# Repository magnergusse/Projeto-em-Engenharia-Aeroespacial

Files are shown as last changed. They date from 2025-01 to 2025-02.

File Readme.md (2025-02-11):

# Projeto-em-Engenharia-Aeroespacial

[EN]This project consisted on the design and development of aerial vehicles capable of reconfiguring in flight in order to join forces to perform greater tasks. It was not possible to conclude said project but it showed to be a great lesson and stepping stone in this journey, which would not have been possible without the help of my colleague Alexandre Silva and our Professor, Pedro Casau.

[PT] Este projeto consistiu no design e desenvolvimento de veículos aéreos capazes de se reconfigurarem em voo de forma a unirem esforços para a realização de tarefas de maior dimensão. Não foi possível concluir o referido projecto mas revelou-se uma grande lição e um trampolim neste percurso, que não teria sido possível sem a ajuda do meu colega Alexandre Silva e do nosso Professor, Pedro Casau.

<h2>Gallery</h2>
<p align="center">

  <br>
    
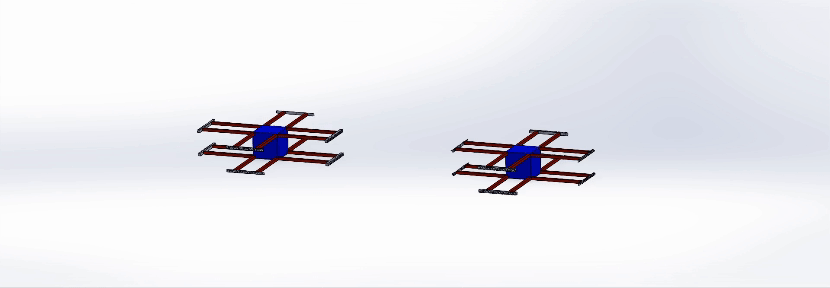
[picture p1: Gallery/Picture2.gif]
    
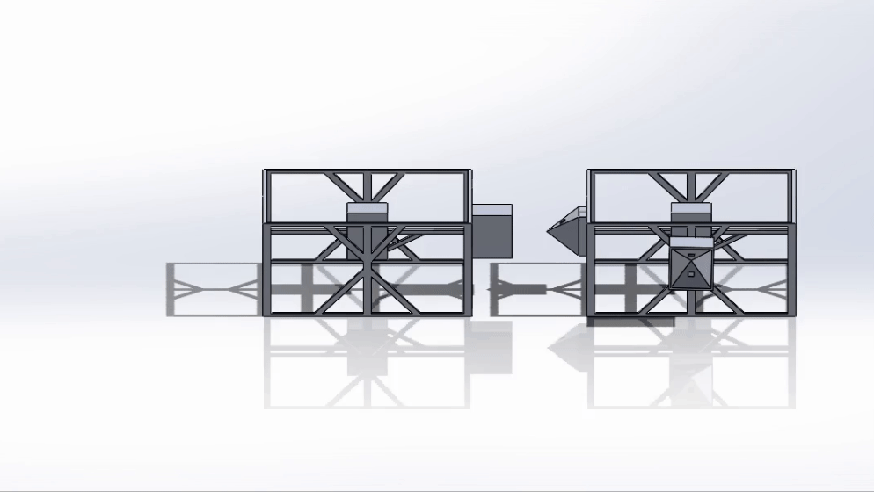
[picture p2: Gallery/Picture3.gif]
    
      <br>
<!---   <a>
  Concept 1   |      
  </a>
  <a>
   Concept 2    |      
  </a> 
  <a>
  Concept 3
  </a>
  --->
  <br>
  
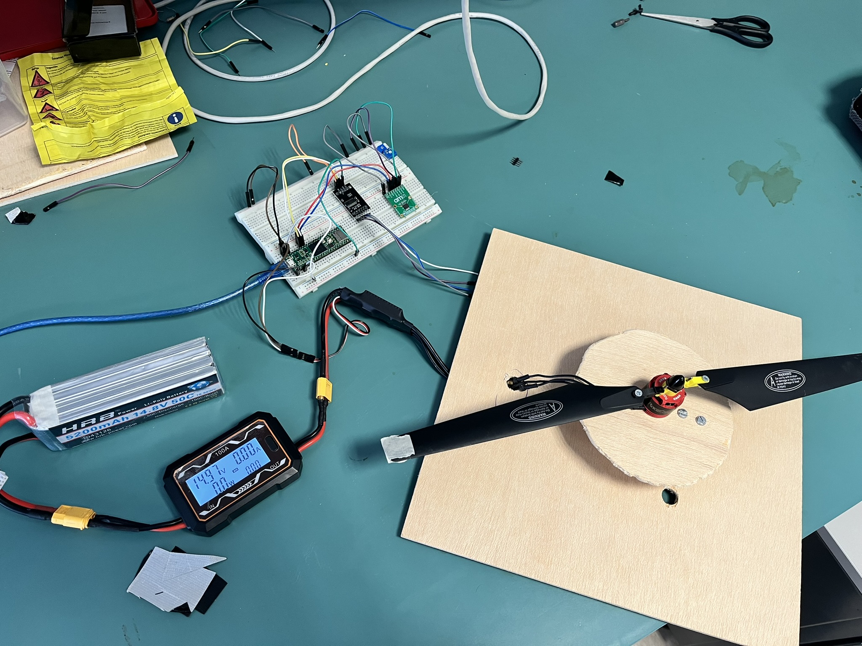
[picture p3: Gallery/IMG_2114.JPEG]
  
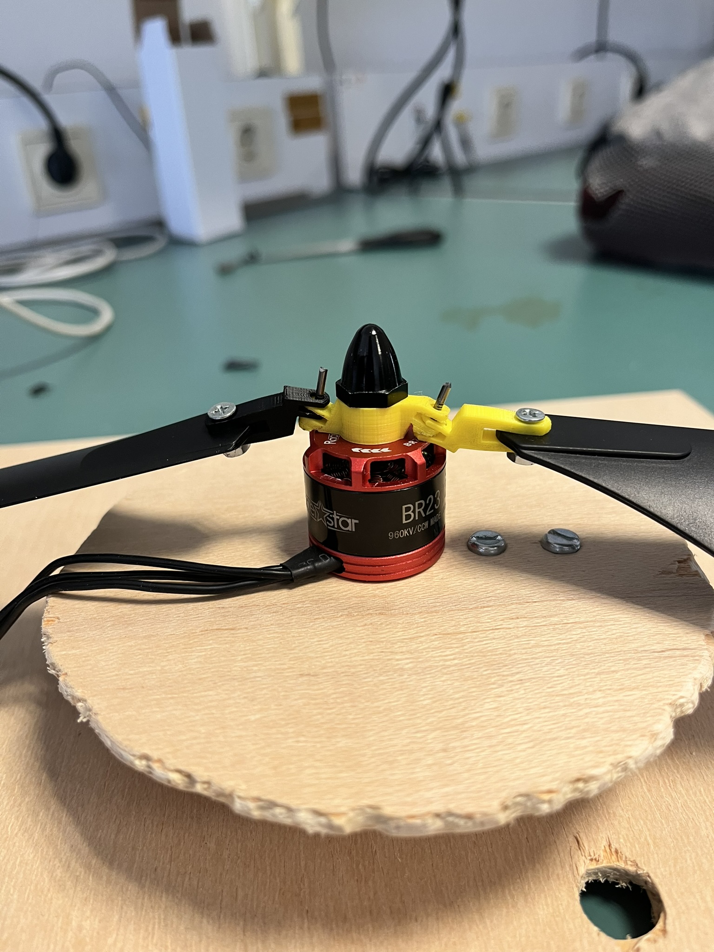
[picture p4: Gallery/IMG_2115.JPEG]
  
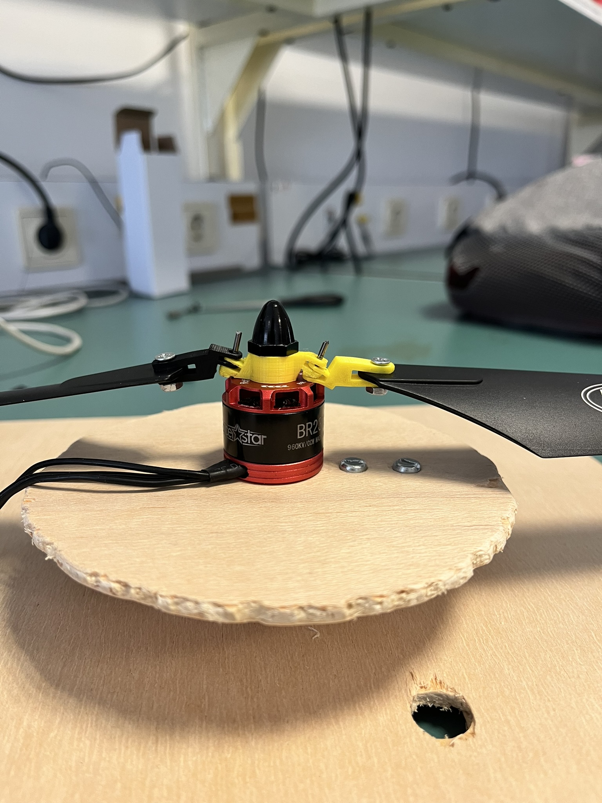
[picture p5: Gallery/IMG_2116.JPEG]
  
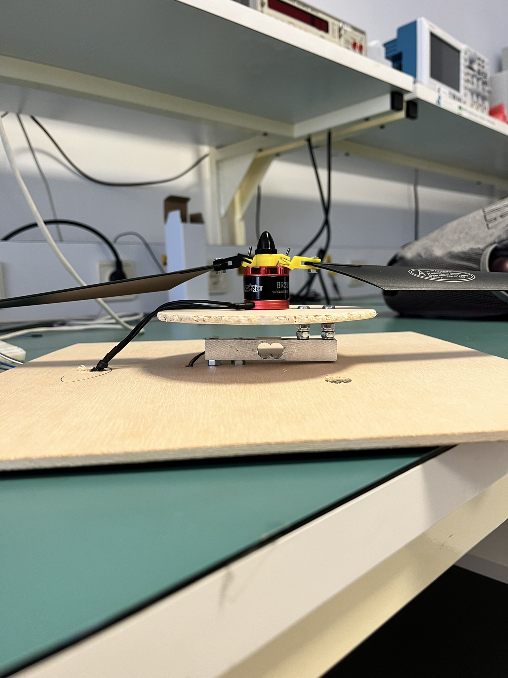
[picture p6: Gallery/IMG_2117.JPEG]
  
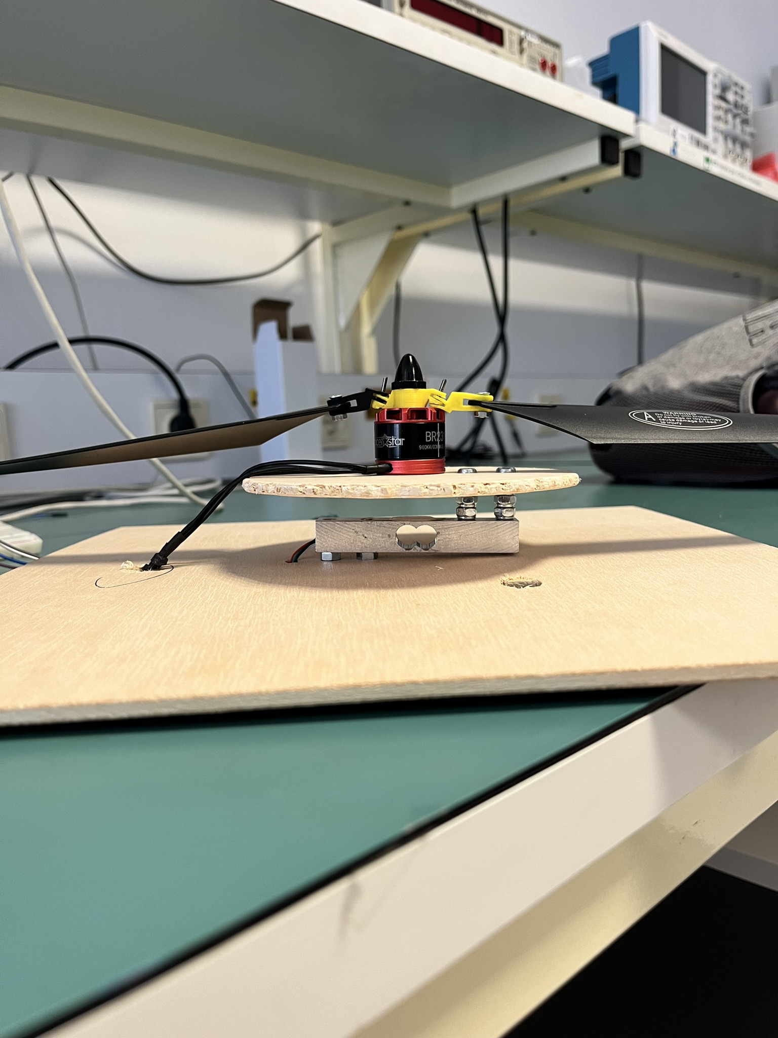
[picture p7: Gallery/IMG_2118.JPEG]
  
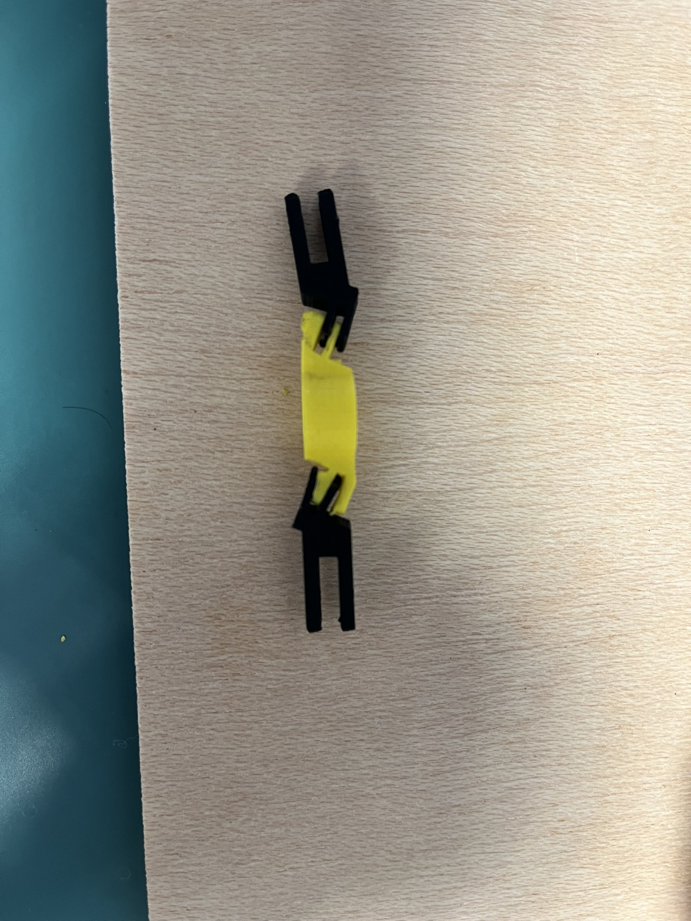
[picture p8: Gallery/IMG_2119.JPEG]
  
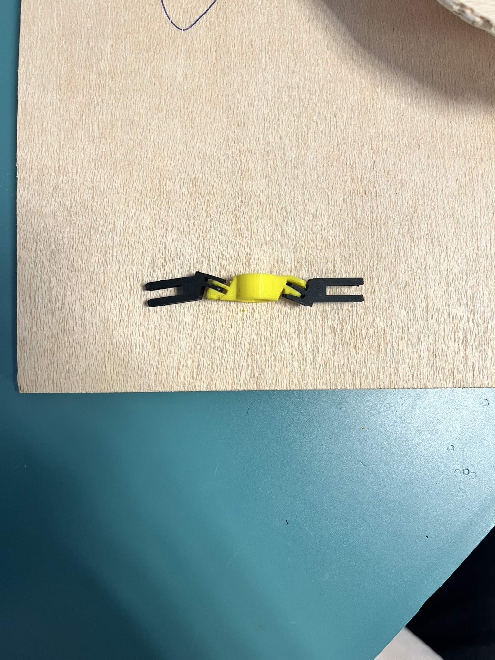
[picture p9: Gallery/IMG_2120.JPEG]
  
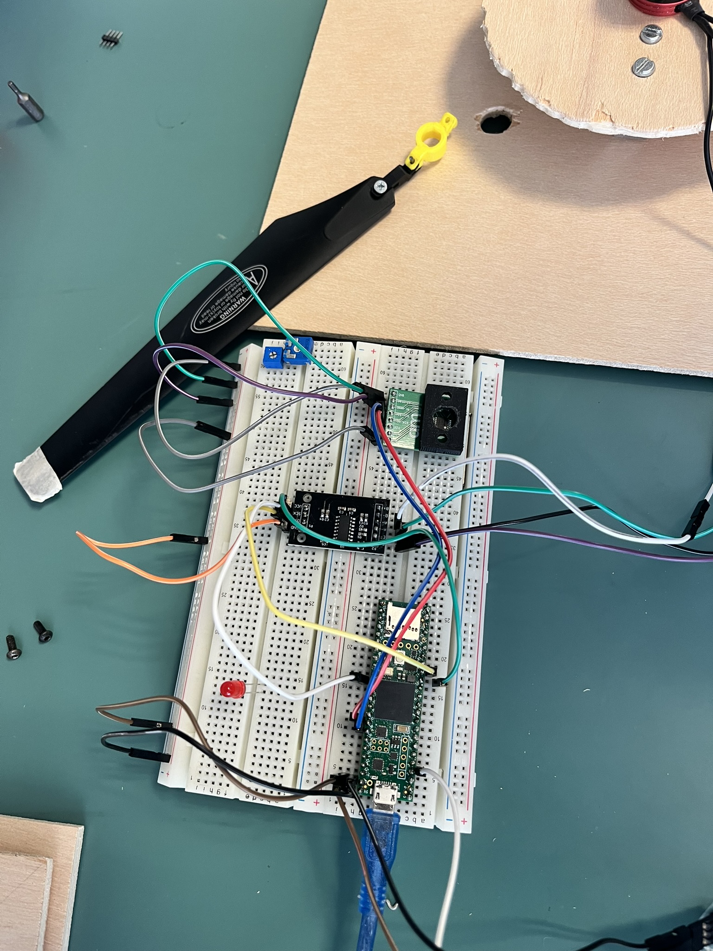
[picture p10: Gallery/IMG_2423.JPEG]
  
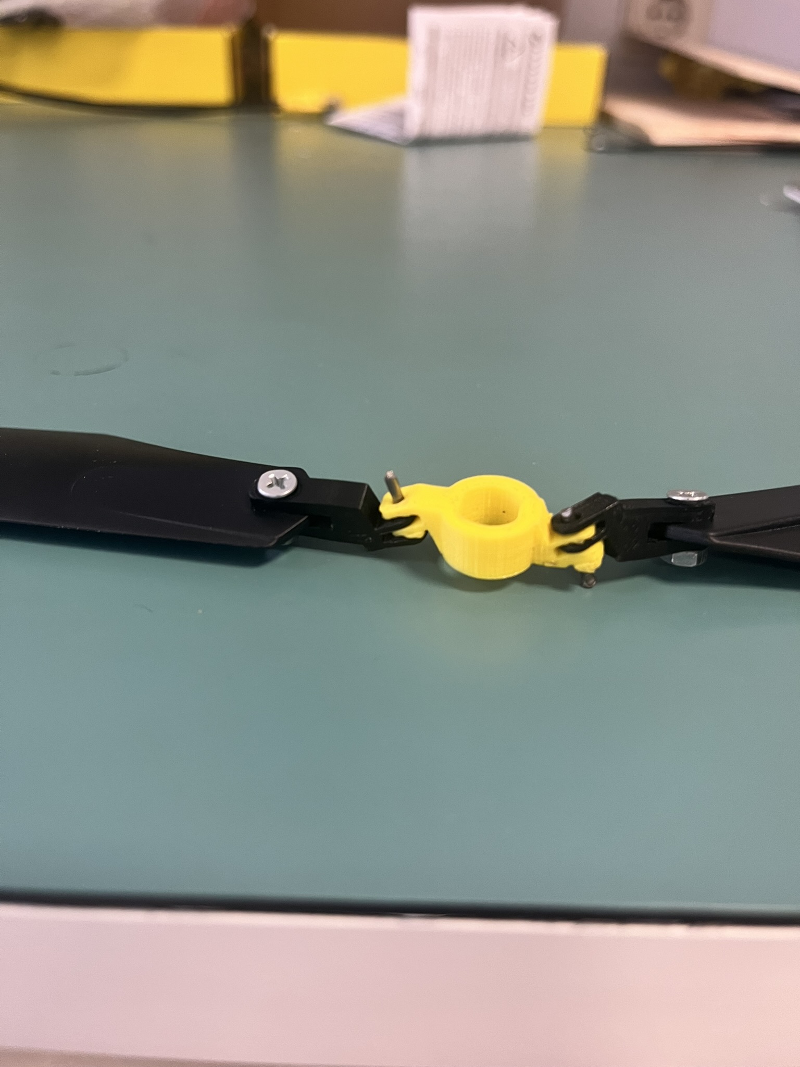
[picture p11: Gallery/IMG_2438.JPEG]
  
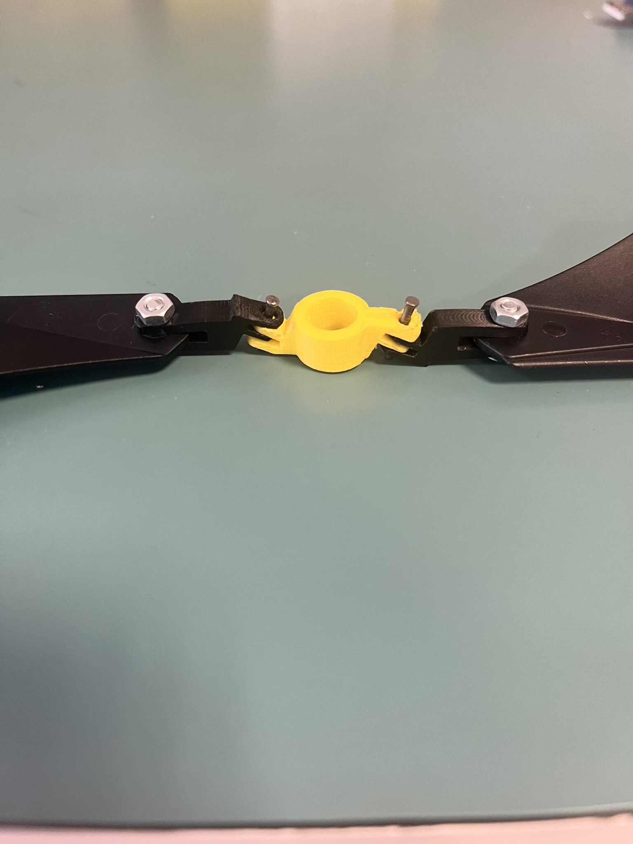
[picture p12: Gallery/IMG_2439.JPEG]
  
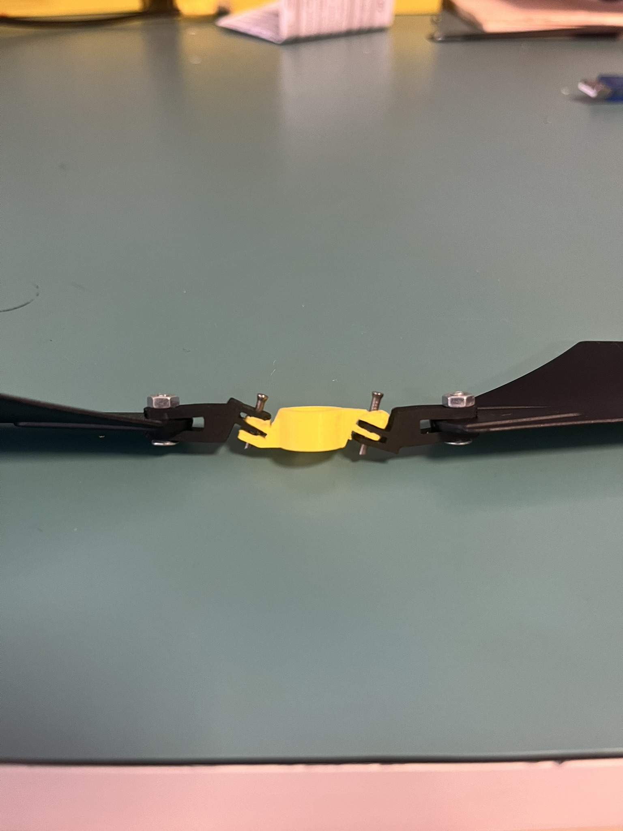
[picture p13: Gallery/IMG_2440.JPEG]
  
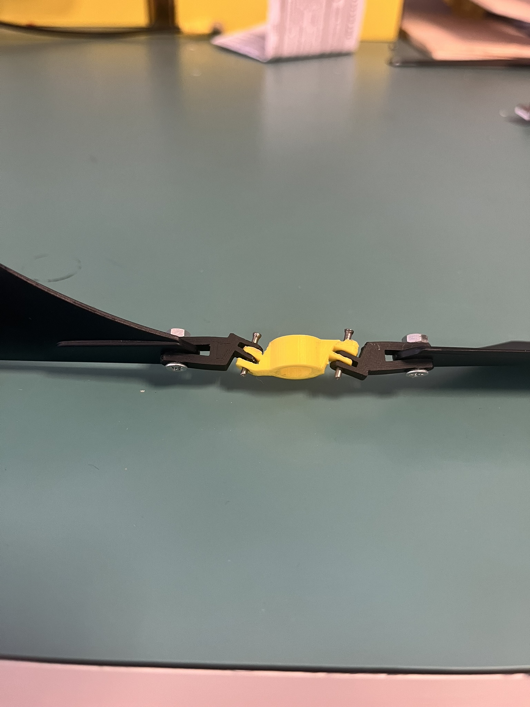
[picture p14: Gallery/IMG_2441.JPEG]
  
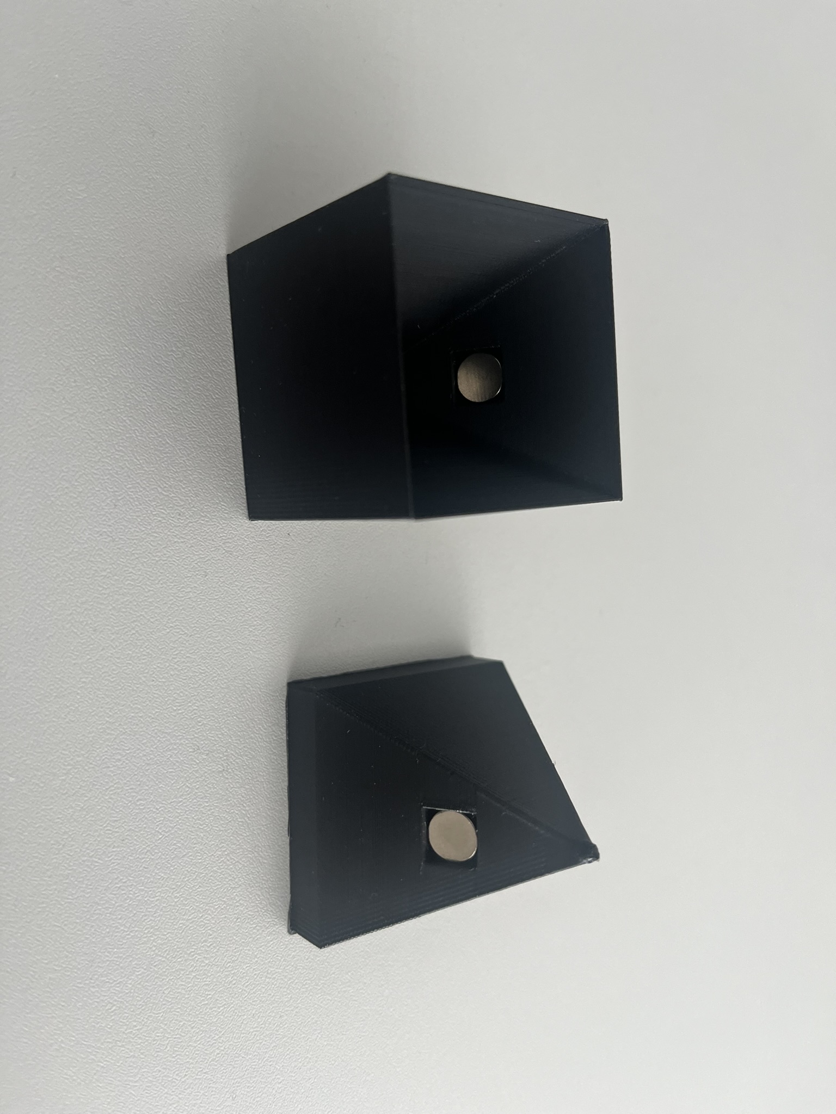
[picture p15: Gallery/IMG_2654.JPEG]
  
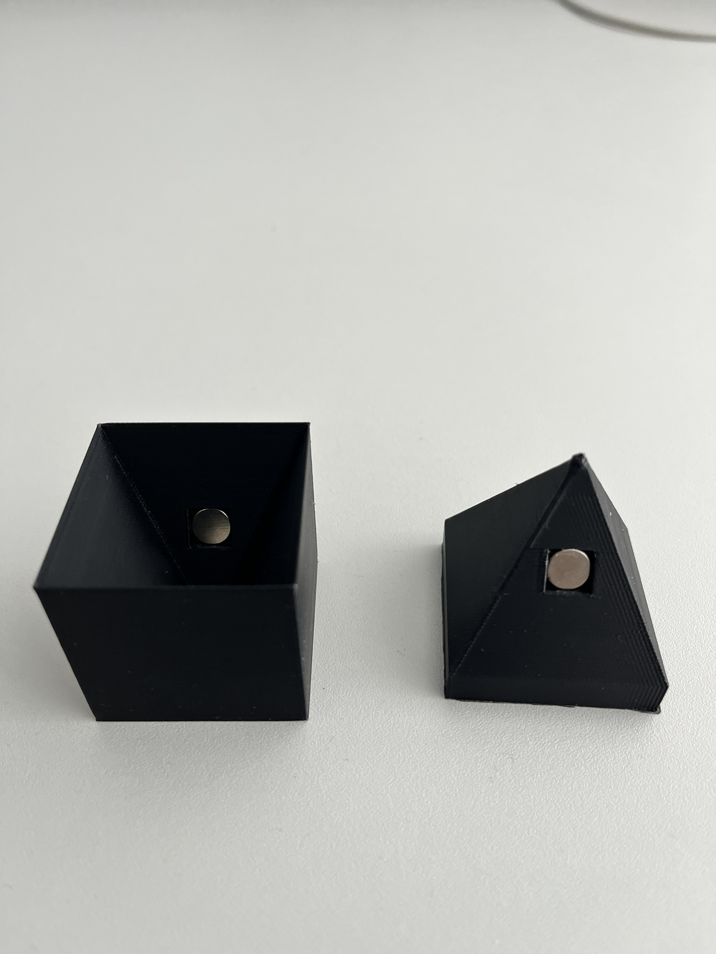
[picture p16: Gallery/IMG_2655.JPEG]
  
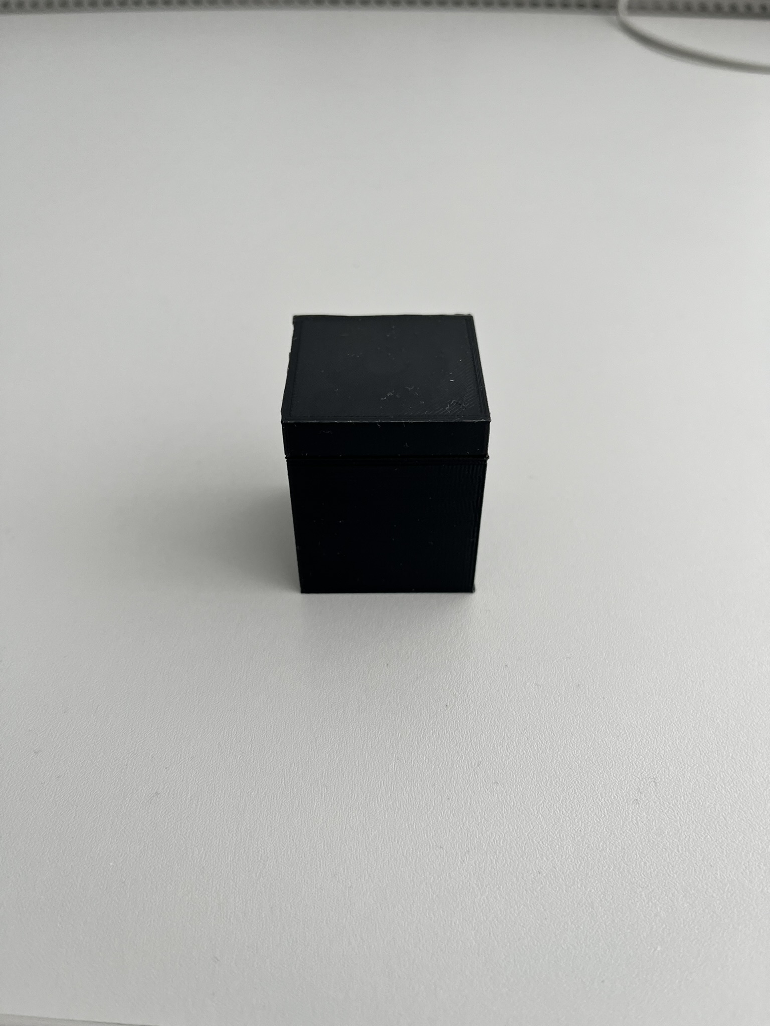
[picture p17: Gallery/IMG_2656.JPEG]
  
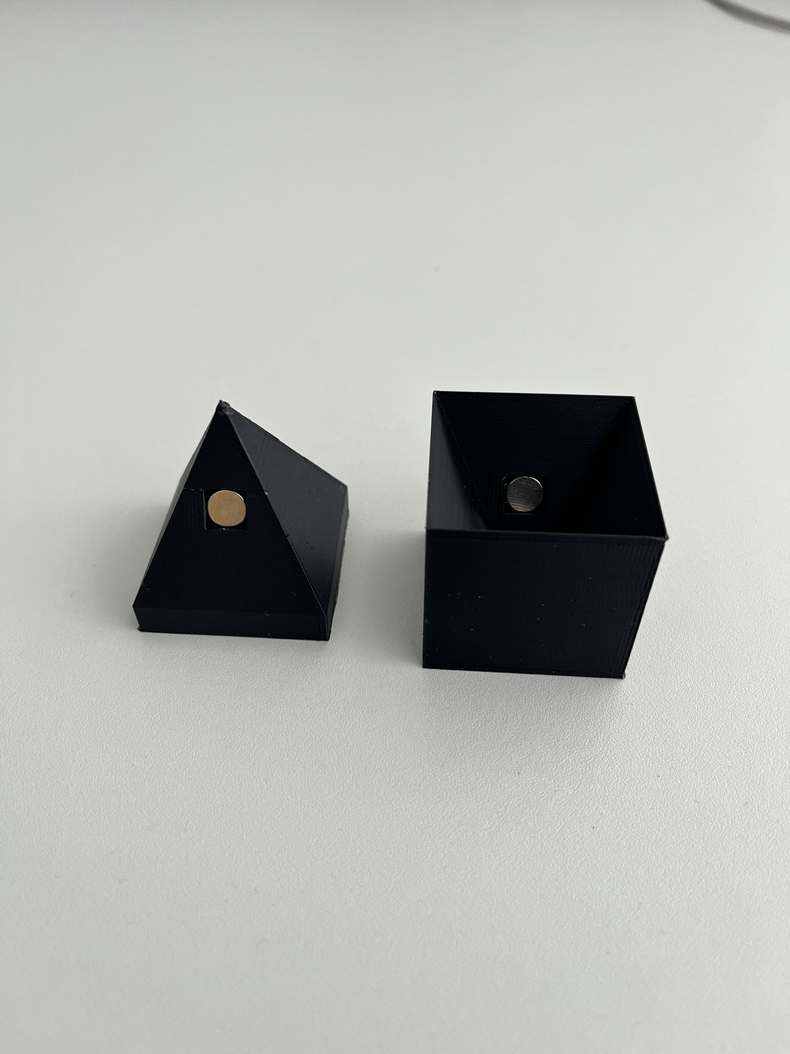
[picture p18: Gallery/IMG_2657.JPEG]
  
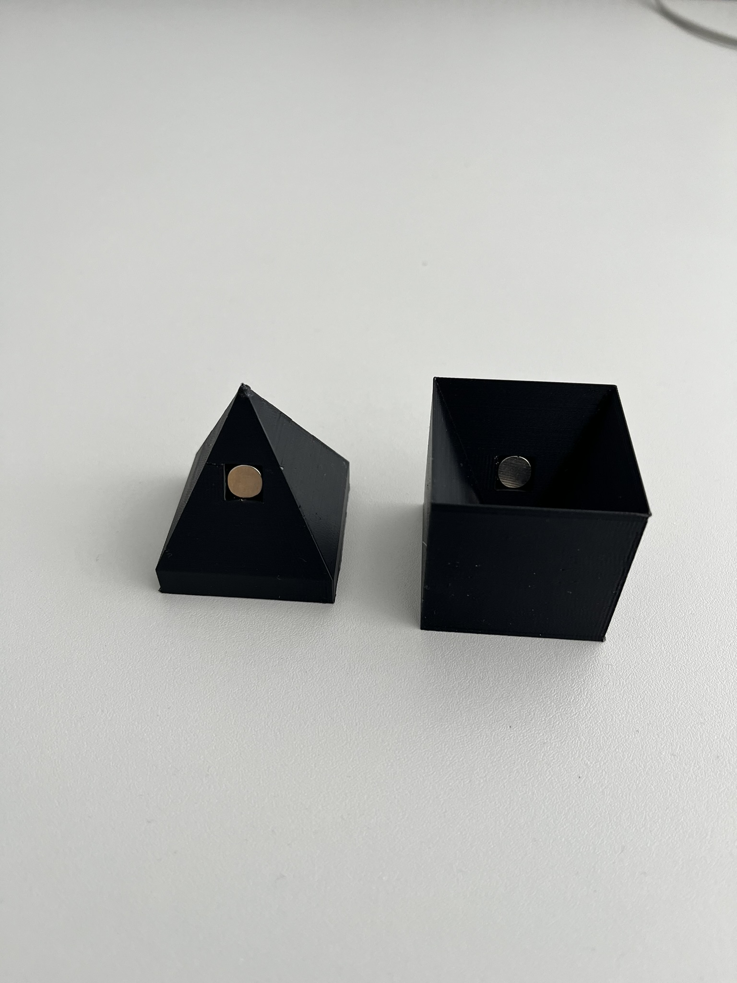
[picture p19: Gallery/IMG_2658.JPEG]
  
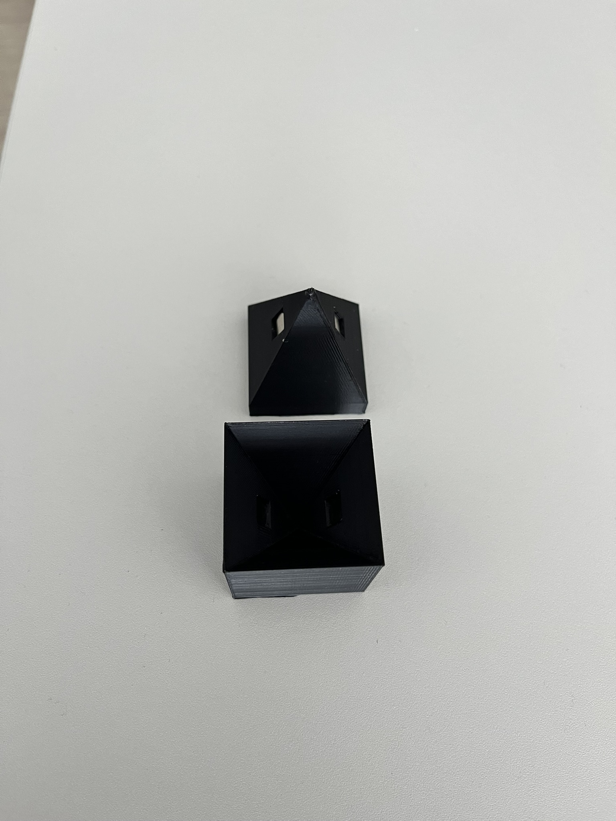
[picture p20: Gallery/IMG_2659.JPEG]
  
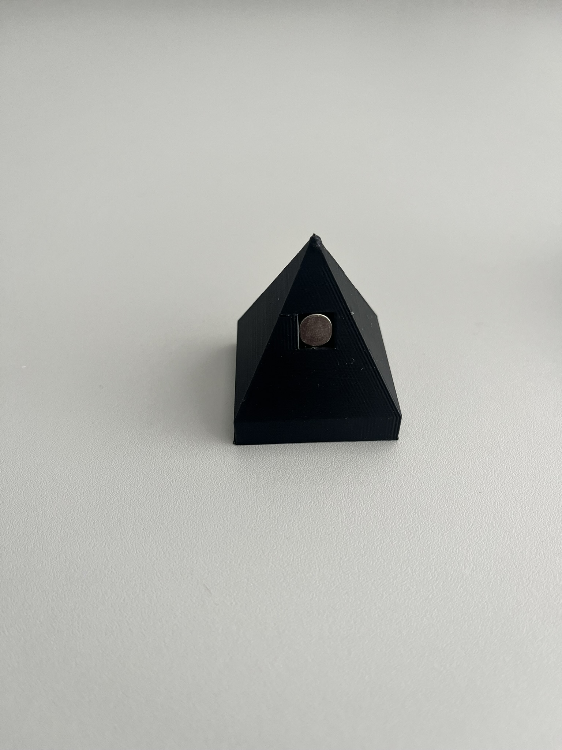
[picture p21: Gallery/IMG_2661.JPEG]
  
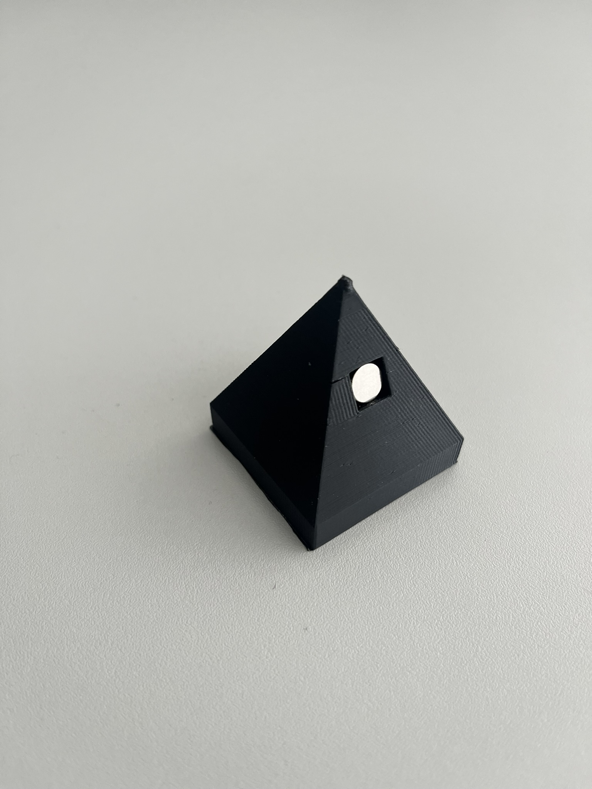
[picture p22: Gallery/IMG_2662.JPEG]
  
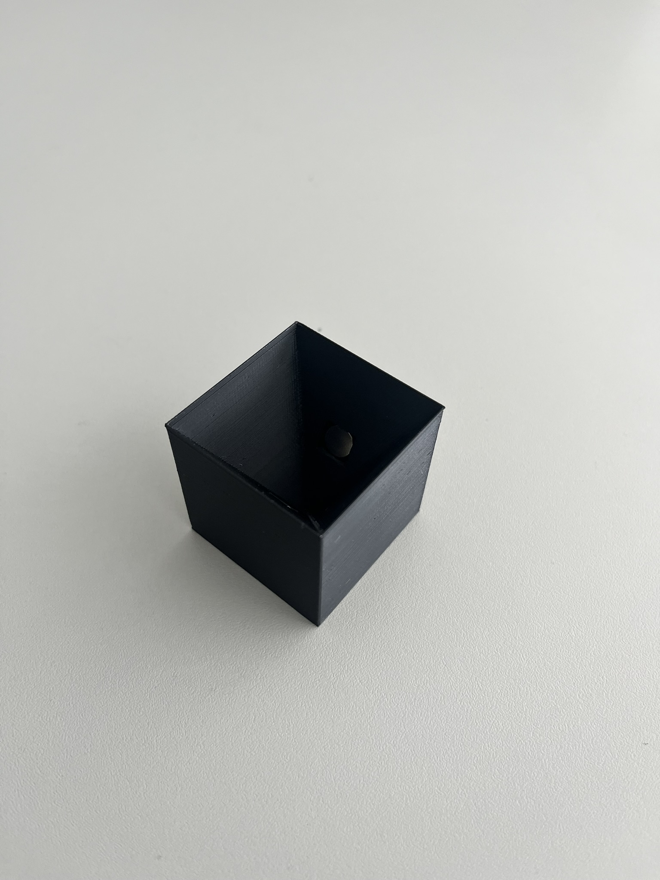
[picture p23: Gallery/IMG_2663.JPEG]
  
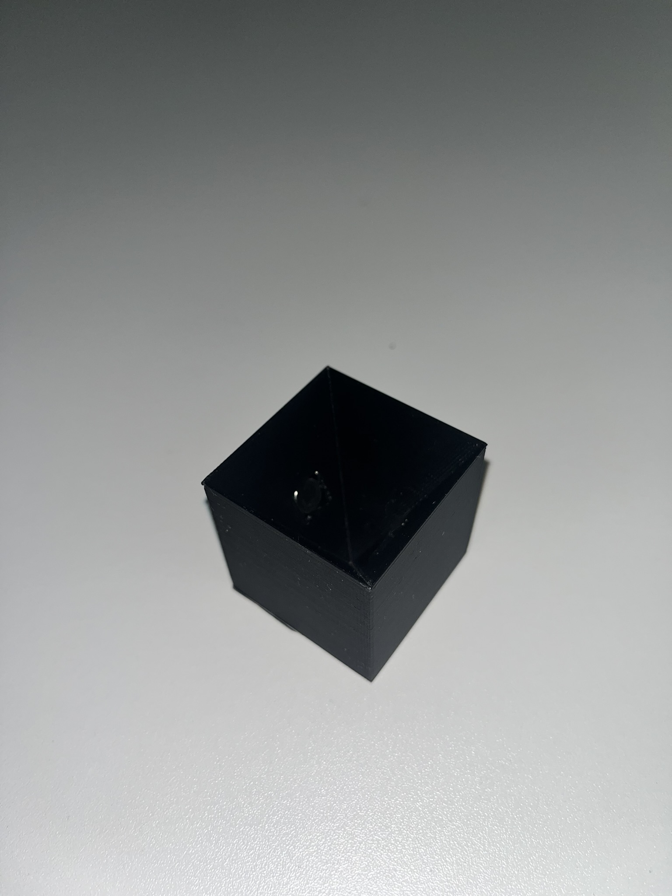
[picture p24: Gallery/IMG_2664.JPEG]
  
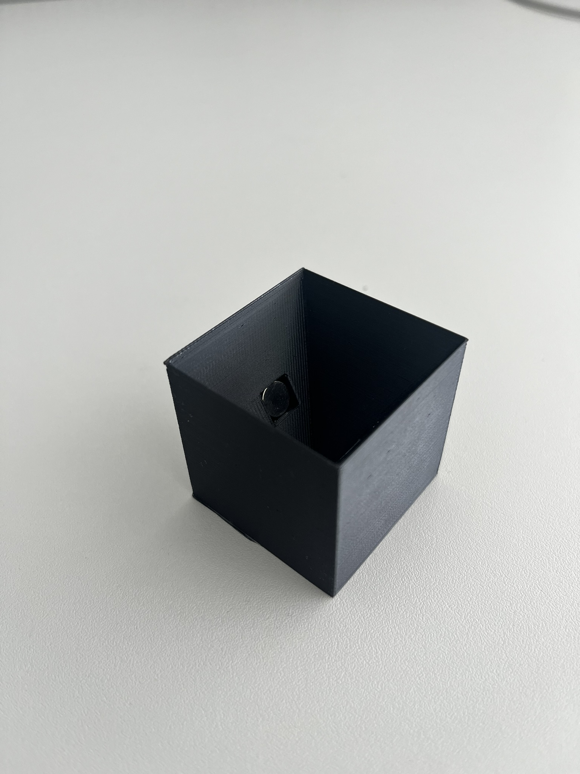
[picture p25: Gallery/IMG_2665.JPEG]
  
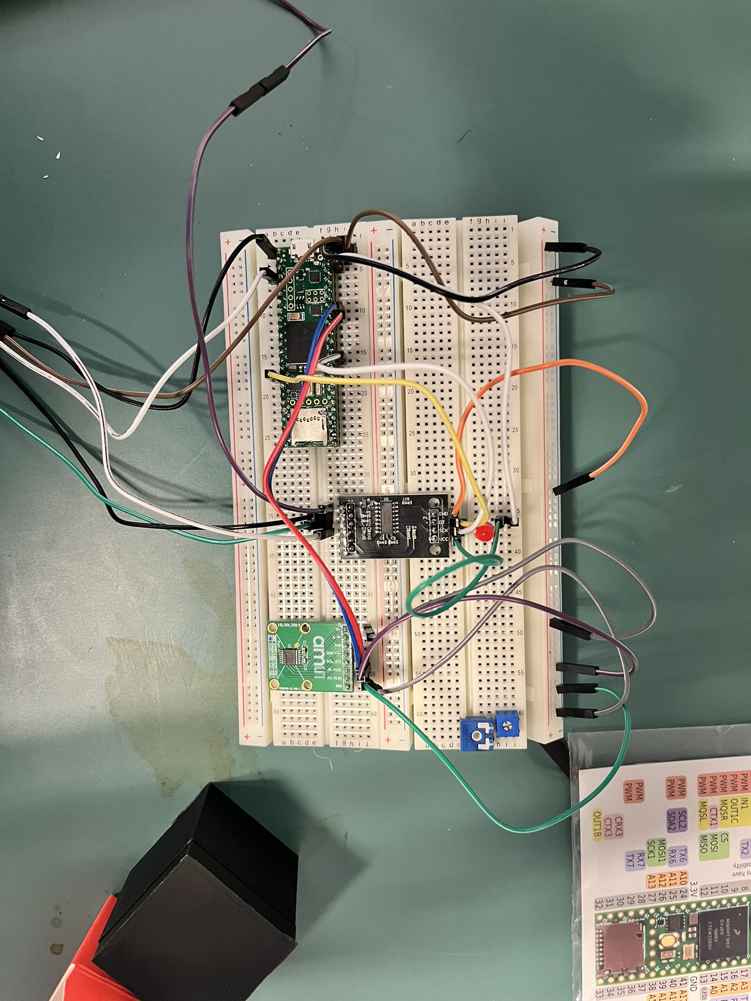
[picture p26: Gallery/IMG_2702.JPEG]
  
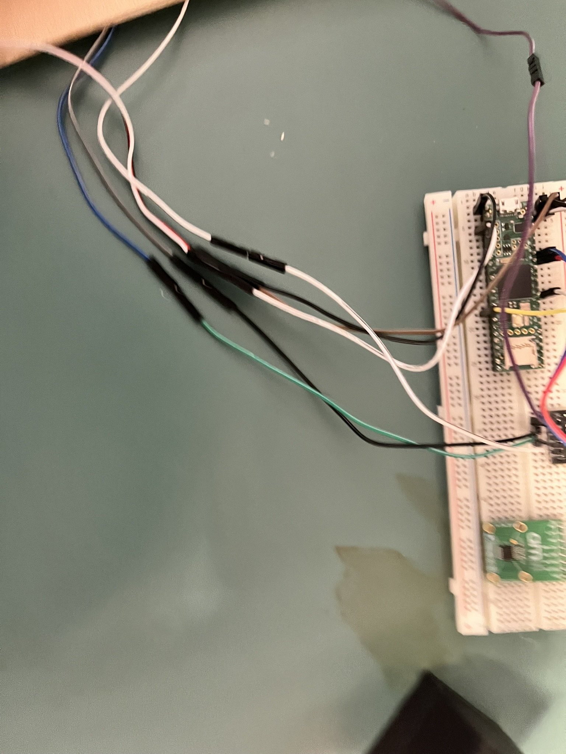
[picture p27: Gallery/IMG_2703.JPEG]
  
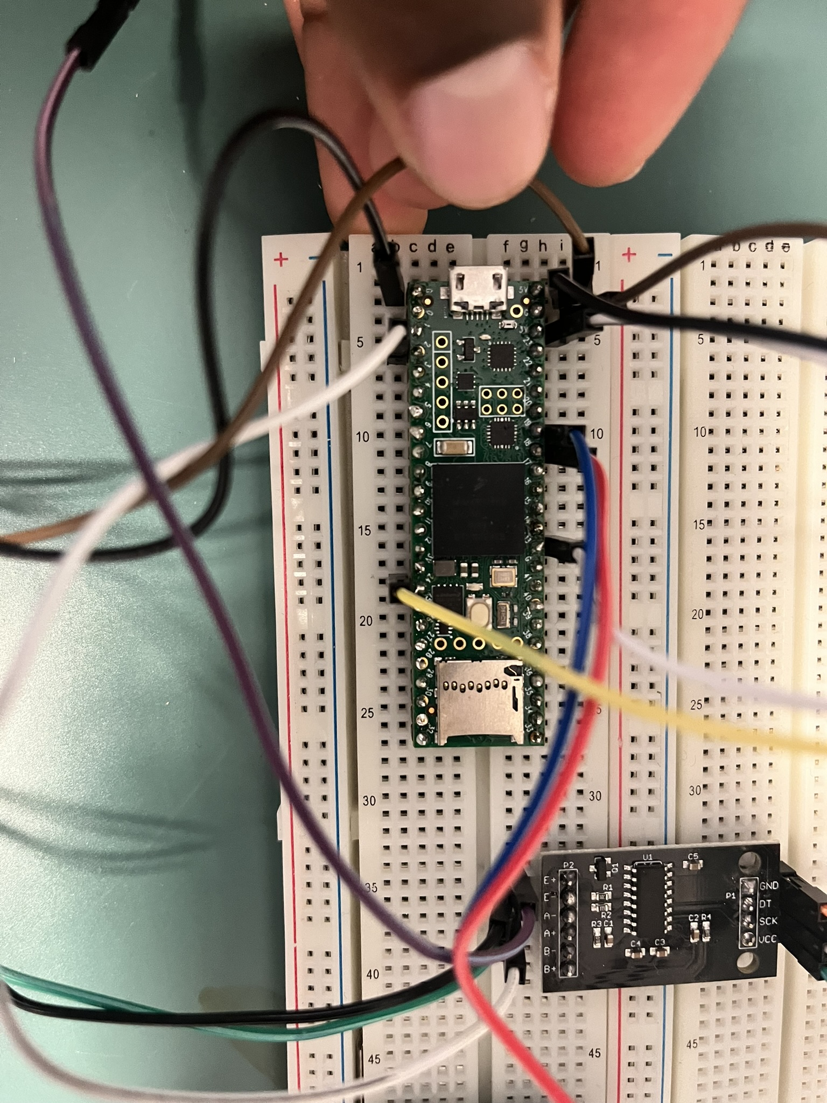
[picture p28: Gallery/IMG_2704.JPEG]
  
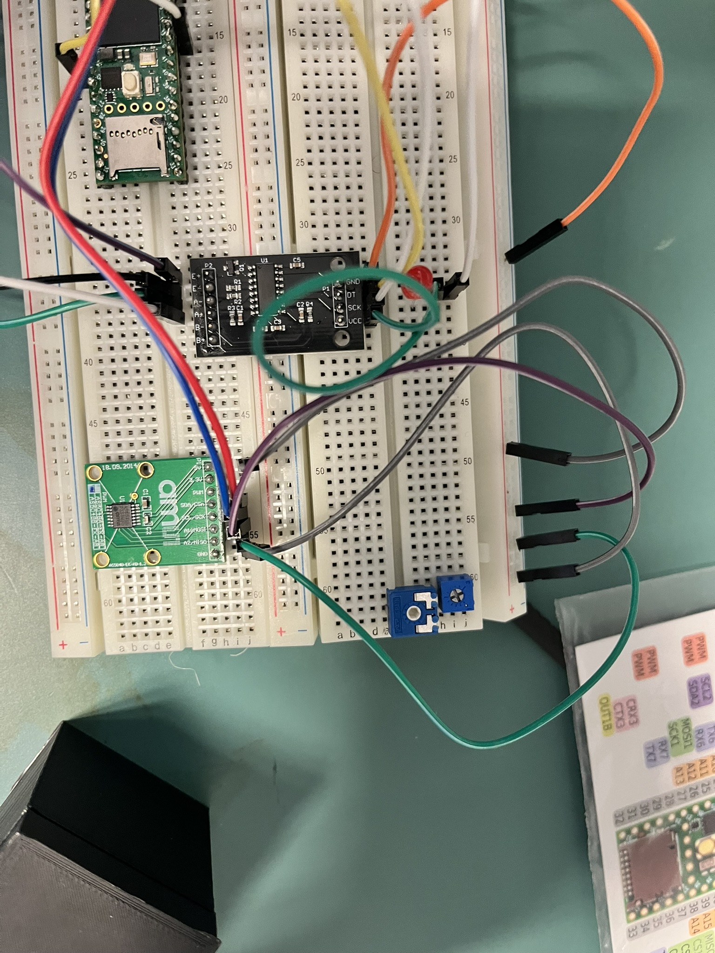
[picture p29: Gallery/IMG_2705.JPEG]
  
  
</p>

<h2>Videos</h2>
  <p align="center">

   <a href="https://youtube.com/shorts/ozo2lfBxjCk?feature=share" target="_blank">
     
  </a>
  
  <a href="https://youtube.com/shorts/JcyohlVHpi4?feature=share" target="_blank">
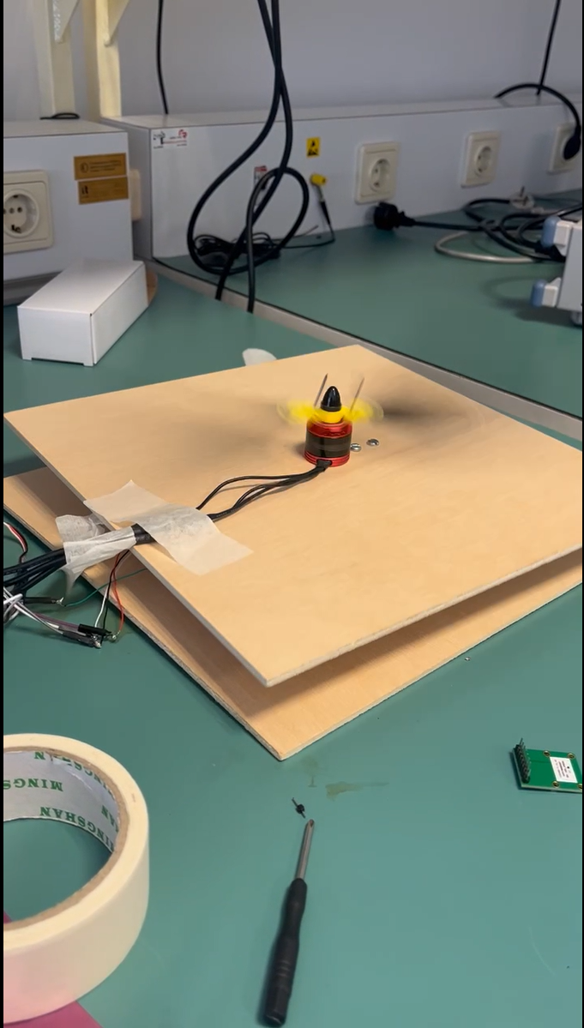
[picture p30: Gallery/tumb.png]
    
  </a>
  
  <a href="https://youtube.com/shorts/KsTUEmDCxvE?feature=share" target="_blank">
    
  </a>
  <br>
   <a>
    Reconfiguration Mechanism    |      
  </a>
  
  <a>
      Thrust Stand 1    |      
  </a>
  
  <a>
      Thrust Stand 2
  </a>
</p>

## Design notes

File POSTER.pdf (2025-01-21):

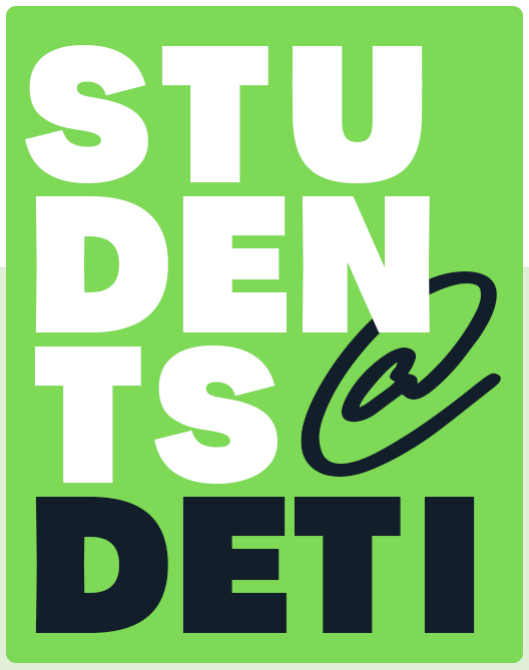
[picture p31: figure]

# Development of Modular Aerial reconfigurable Vehicles

## Alexandre Silva, Magner Gusse Orientador: Prof. Pedro Casau

Projeto em Engenharia Aeroepacial, 3º ano, LEA.
2024

Abstract

This study proposes the development of a modular reconfigurable aerial vehicle. Simply, this project is proposes the creation of 2 aerial vehicles that can attach to each other. Some of the challenges and objectives of this study were the use of coaxial rotors using Swashplateless[1] system which was the focal point of this project.

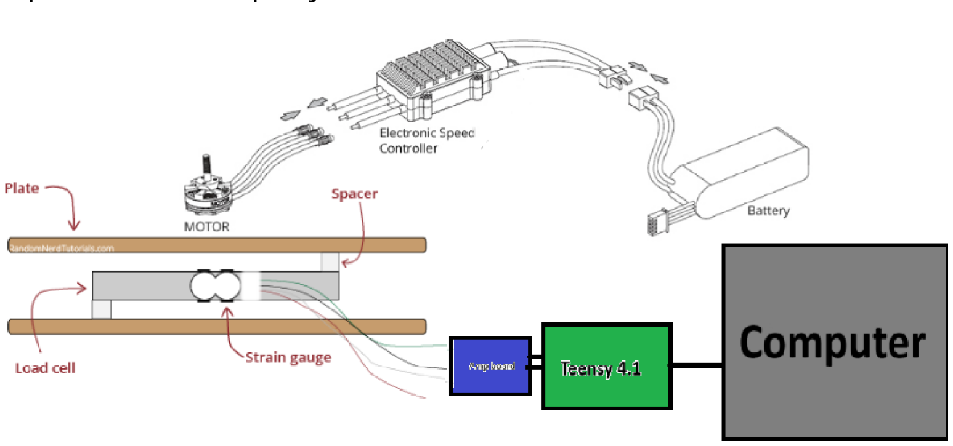
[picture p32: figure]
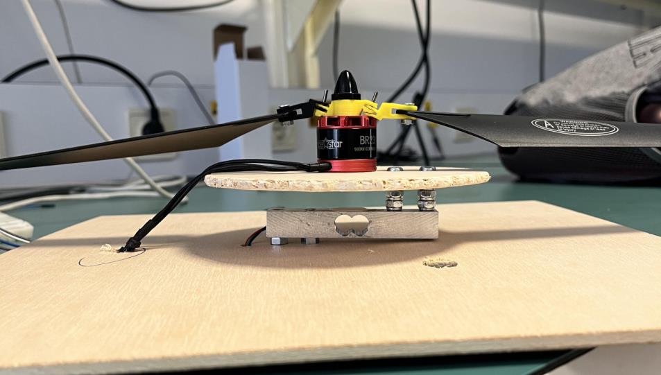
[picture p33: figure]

Fig 1- Thrust Stand Setup
a)Schematic | b)Actual setup

Methods
One of the objectives of this project was to implement coaxial rotors for propulsion and Swashplateless system for direction.
- It was necessary to use helicopter blades instead of regular drone blades, in addition, based on research over the configurations to implement on the model of the system
- The configuration chosen was 65º, which is considered the one that is easier to command and understand[2].
The steps towards determining the propulsion of the system, were to implement a thrust stand with a simple design, using a teensy 4.1 microcontroller, a load cell, wood plates, the motor, blades, the Swashplateless design and a breadboard for all electronics[Fig 1].

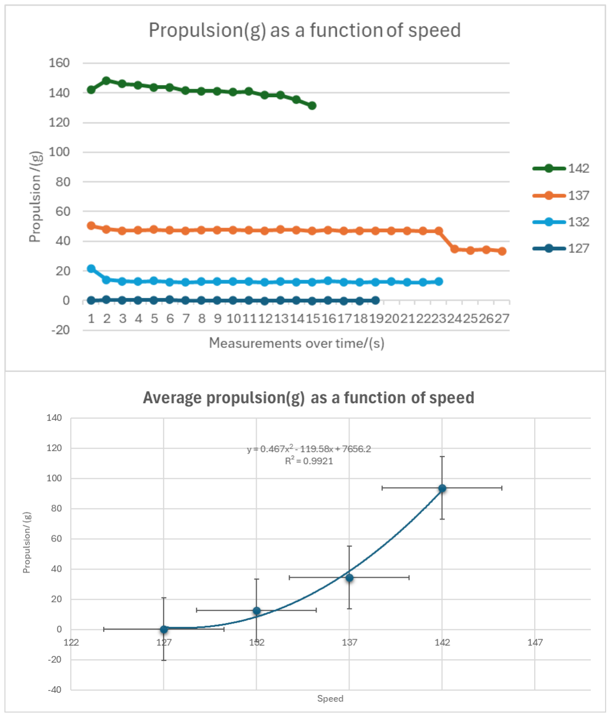
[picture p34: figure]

With this setup it was possible to extract data from series of tests and determine the curve between the propulsion and the power of the motor, from which is possible to predict the maximum thrust possible with this combination of motor and propellers [Fig 2].
To further use the Swashplateless system , it is necessary to have a magnetic encoder to determine the motor angle which would further be used for the control of the pitch and roll movements of the system.
Conclusion
- It was possible to learn how the Swashplateless system can be implemented, by studying the necessary components and different model structures.
- The propulsion curve for the combination of motor and blades was determined using the thrust stand.
This project represents a great learning curve for the involved and sets stones for further implementations. References
[1] Paulos, J., & Yim, M. (Year). Flight Performance of a Swashplateless Micro Air Vehicle.
[2] Stanton, T. (2020). Drone Helicopter Hybrid https://www.youtube.com/watch?v=d80oXSCcHTk

Fig 2- Thrust tests results.

a)

b)

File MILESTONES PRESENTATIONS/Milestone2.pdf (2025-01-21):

Milestone 2

# Design and Development of a Modular Reconfigurable Aerial Vehicle

Grupo 6
107957 – Alexandre Silva
110180 – Magner Gusse

12/12/2023

Pedro Casau

Orientador:

# Conteúdos

Contexto 1 Contextualização da missão,

Objetivos e requisitos | 3

### Progressos

Estado atual do projeto

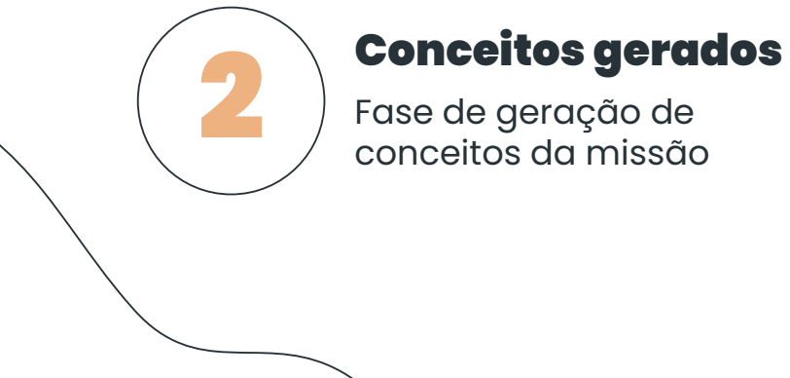
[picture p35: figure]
Conceitos gerados Fase de geração de conceitos da missão

4

### Próximos passos

Testes e objetivos a
alcançar nas próximas
fases

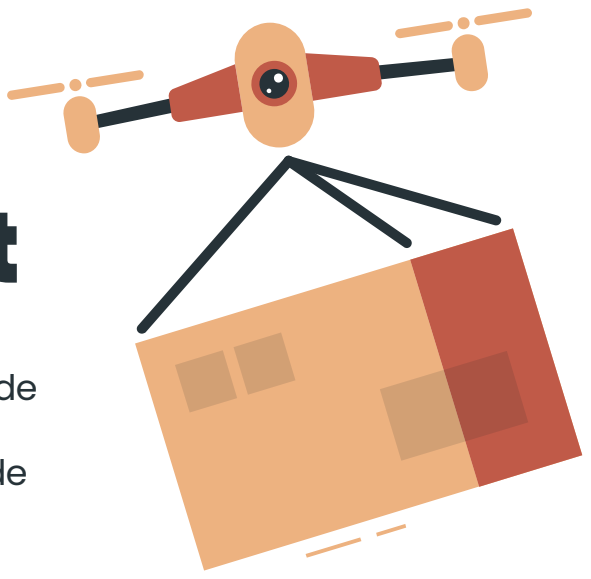
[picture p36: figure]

# Mission Statement

Construção de veículos aéreos que funcionam de forma individual, capazes de se juntar em voo formando configurações diferentes e capazes de em conjunto realizar diversas tarefas.

Primários:

- Desenvolver dois módulos independentes e capazes de realizar as reconfigurações em voo.
- Estudo, comparação e seleção dos métodos de acoplamento de módulos. Secundários:
- Rotores uni-axiais(Counter-Rotating).
- Demonstrar princípio científico e aplicabilidade.
- Otimização da estrutura.
- Extra: Ligação de um Payload.

# Objetivos

# Requisitos

1

### Performance

❑ Voo estável e controlado ❑ Reconfiguração em voo
❑ 6 graus de Liberdade
❑ Sistema Swashplateless

2

### Fiabilidade

❑ 10 minutos de voo
❑ Estrutura resistente
❑ Aviónica protegida
❑ Reutilizável

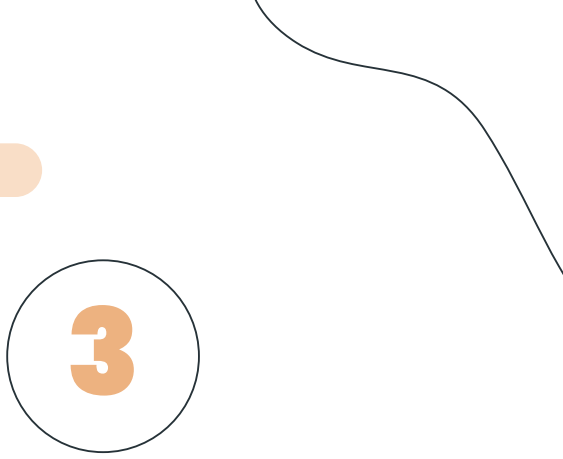
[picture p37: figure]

### Design

❑ Simplicidade de Design
❑ Fácil montagem
❑ Fácil manutenção

# Geração de conceitos

### Ligação entre módulos

Criação de propostas
para a ligação entre os
veículos

### Swashplateless

Criação de propostas
para o sistema que irá
direcionar os veículos.

1 2

# Conceitos de Ligação

### Vantagens

- Estabilidade de voo
- Massa reduzida

### Desvantagens

- Mais difícil de efetuar a ligação

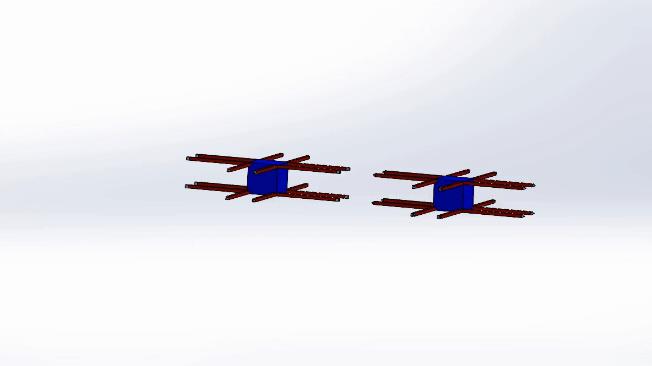
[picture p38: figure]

Conceito 1

# Conceitos de Ligação

### Vantagens

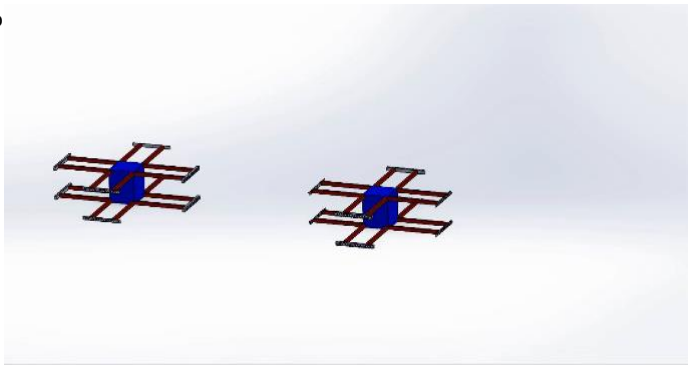
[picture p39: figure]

- Maior estabilidade de voo

### Desvantagens

- Difícil de efetuar a
ligação
- Possui mais massa

Conceito 2

# Conceitos de Ligação

### Vantagens

- Facilidade de ligação

### Desvantagens

- Menor estabilidade
- Maior massa

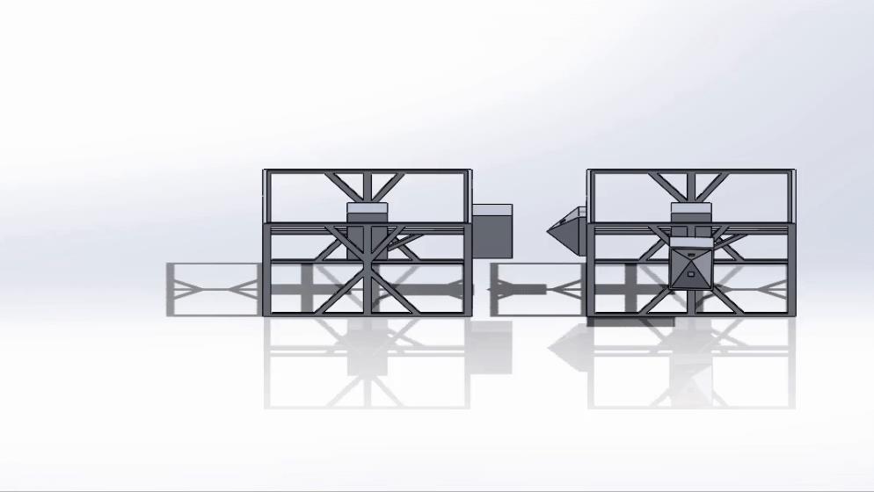
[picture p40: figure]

Conceito 3

# Conceitos de Ligação

### Estrutura da ligação

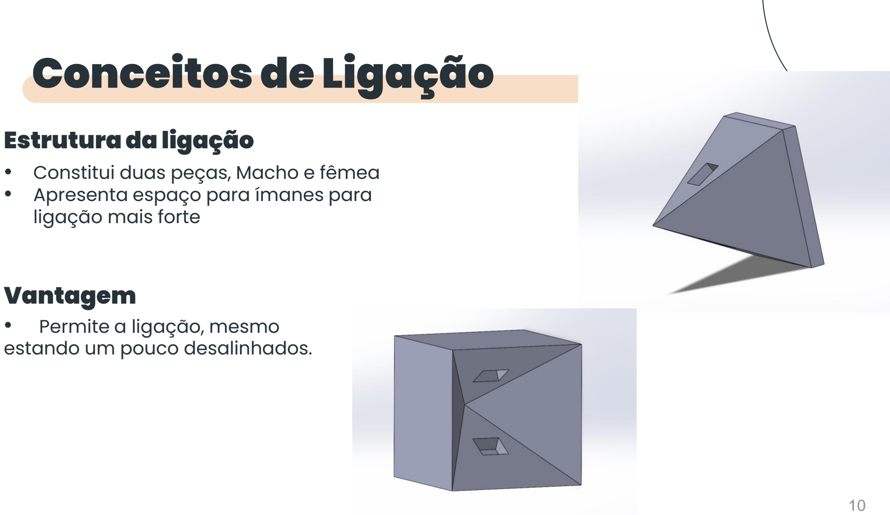
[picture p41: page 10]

- Constitui duas peças, Macho e fêmea
- Apresenta espaço para ímanes para ligação mais forte

### Vantagem

- Permite a ligação, mesmo estando um pouco desalinhados.

# Conceitos do Swashplateless

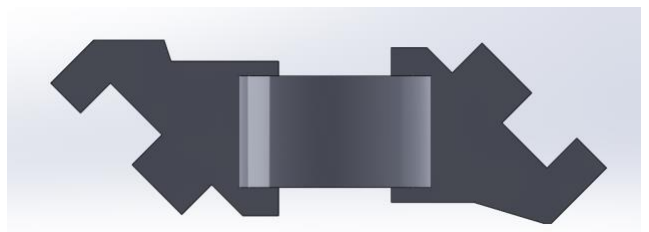
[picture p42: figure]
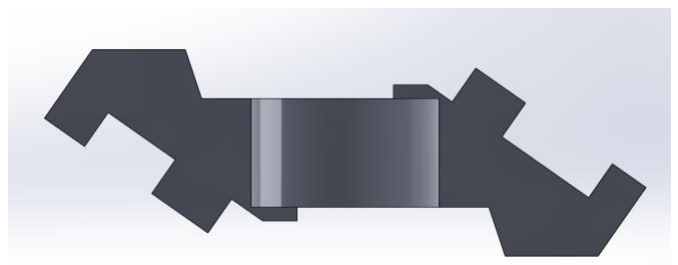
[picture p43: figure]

45º | 35º

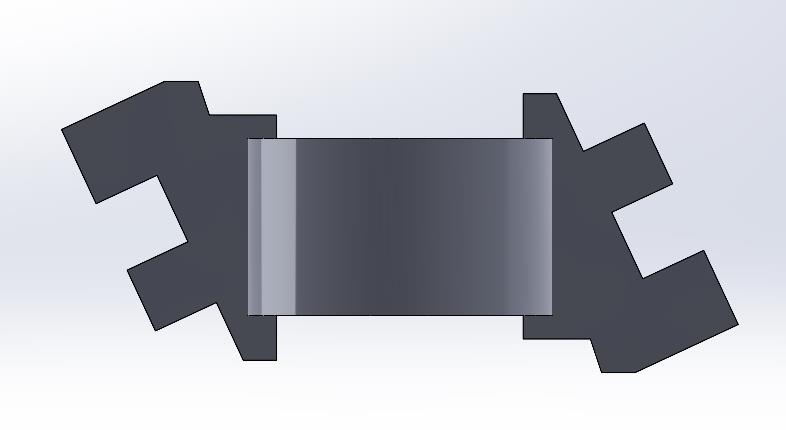
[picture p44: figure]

65º

Ângulo | Tuning | Motor Load
Maior | Fácil | Maior
Menor | Difícil | Menor

# Swashplateless

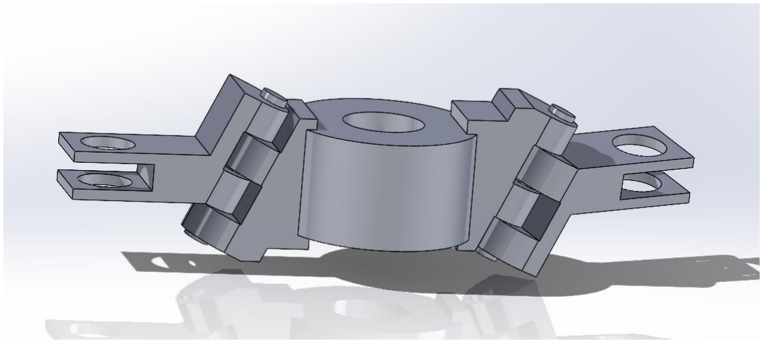
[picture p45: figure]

### Microcontrolador

# Listagem de componentes

### Bateria

### Rotores

### Hélices

4s e 5200 mAh

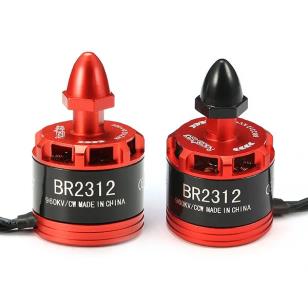
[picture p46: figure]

Brushless 1250KV

19cm de comprimento

Teensy 4.1

### Recetor

# Listagem de componentes

### Speed Controller

### Sensor de posição angular

### Transmissor

HobbyKing 50A

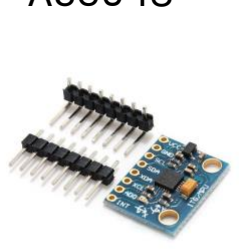
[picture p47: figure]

AS5048

FS-i6X 2.4GHz

FS-iA6B 2.4GHz

# Componentes - Massa

Componente | Qtn. | Mass(g) p/unit
Rotor | 2 | 68
ESC | 2 | 82
Teensy 4.1 | 1 | 12
Bateria | 1 | 475
Recetor | 1 | 15
Sensor | 1 | 5
Cables | n | 15
Helices | 4 | 11
Swashplateless | 1 | 10
Total | | 876

1 Módulo
Para a potência máxima de um motor, usando hélices menores, garante-se propulsão de 1200g e o requisito de 10 minutos de voo

# Arquitetura

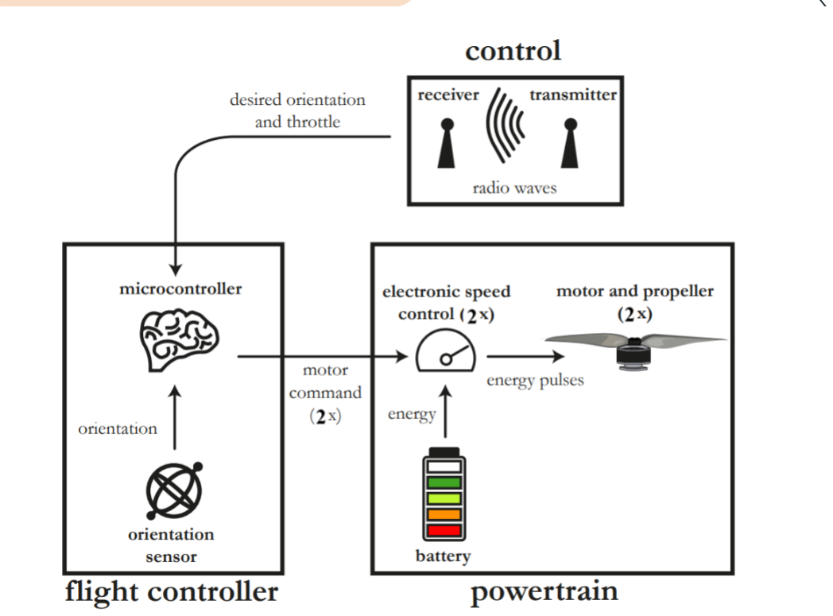
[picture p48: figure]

### Esquematização

Esquema funcional da
arquitetura eletrónica a
seguir em ambos veículos.

# Arquitetura

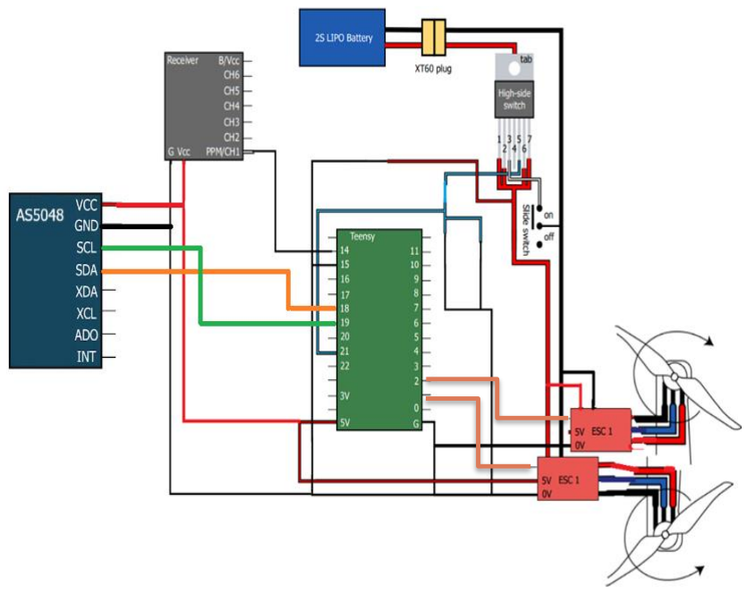
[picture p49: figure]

### Ligações dos componentes

Ligação esquematica e funcional dos componentes escolhidos.

# Work Breakdown Structure

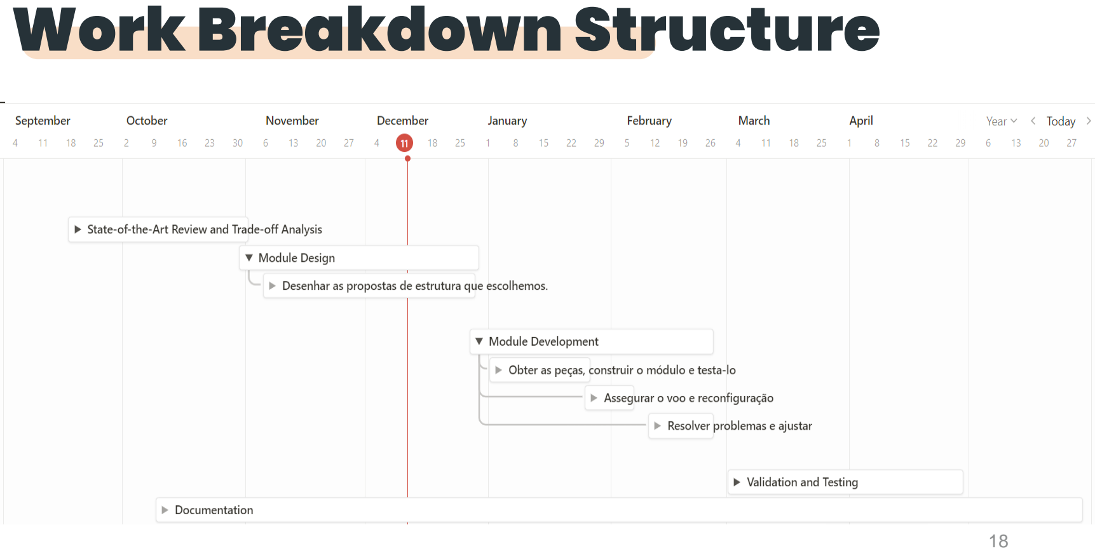
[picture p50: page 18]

# Cumprimento de tarefas

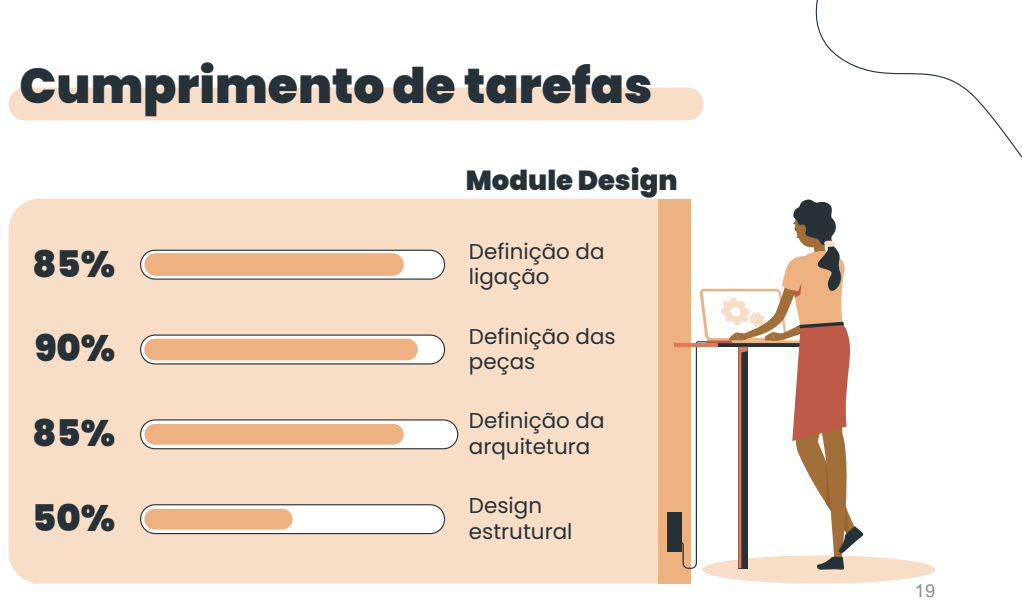
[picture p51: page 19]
Definição da; ligação; Definição das; peças; arquitetura; Design; estrutural; Module Design

# Gestão de recursos

A alocação de recursos humanos de forma a cumprir os objetivos traçados da melhor forma:

Percentagem de
trabalho na tarefa

### Alexandre

### Magner

Percentagem de
trabalho na tarefa

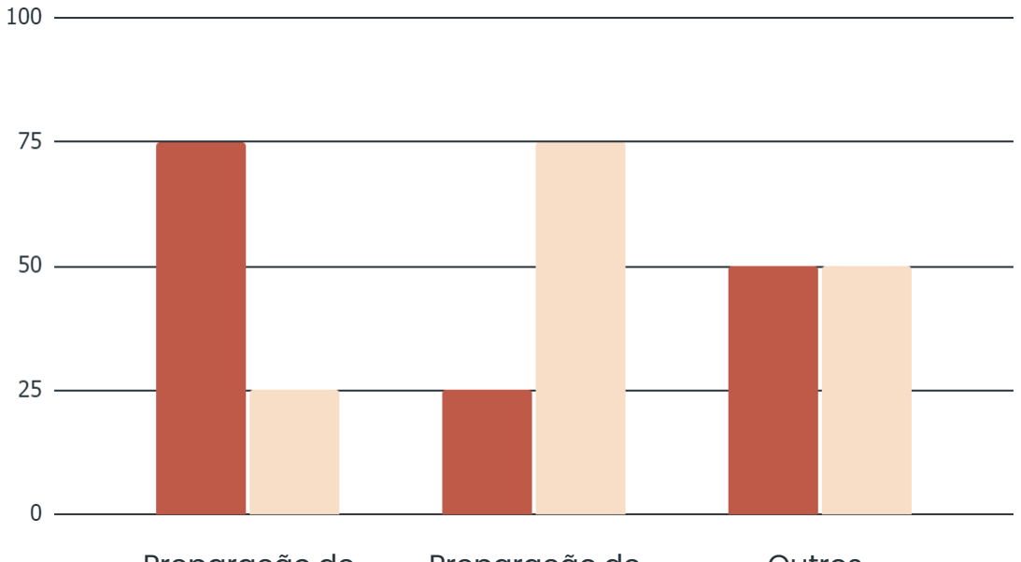
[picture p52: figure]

Preparação de
modelos para a
estrutura

Preparação de
guiões de testes

Outros

# Testes a Realizar

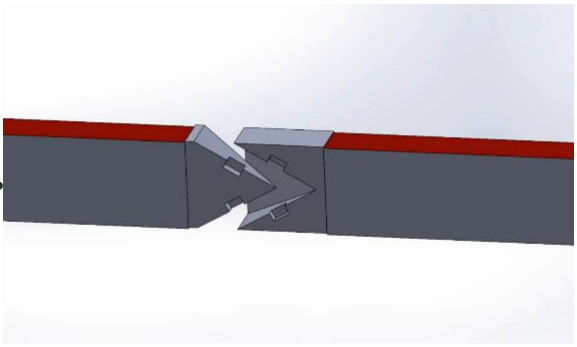
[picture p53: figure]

De forma a determinar
a melhor estrutura para
a ligação entre os
módulos.

### Ligação

# Testes a Realizar

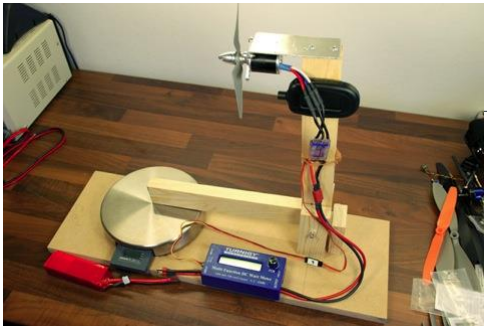
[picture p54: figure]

### Propulsão

Para determinar a carga
máxima que os rotores e
as hélices podem
suportar.
Para ter a noção da
propulsão que o conjunto
oferece em função da
potência dada ao motor.

# Testes a Realizar


Teste de funcionamento
do conceito e das
diferentes variações.

### Swashplateless

Visando cumprir com os
requisitos de performance

https://www.youtube.com/watch?v=aEPf0QHVuMMt=70s
https://www.youtube.com/watch?v=aEPf0QHVuMM&t=70s

# Mitigação dos riscos

Prazos do projeto; arquitetura.; Testes a realizar

Complexidade
técnica
Estudo prévio das ligações
e dos componentes e a
compatibilidade entre
estes.

Divisão de recursos de
forma a cumprir com os
prazos estabelecidos

Reconfiguração
O desacoplamento pode
não acontecer, solução
com eletroimanes.

Para validação dos
componentes críticos da

# Conclusões

Necessária a antecipação de tarefas sempre que possível; Gestão; Arquitetura A escolha de componentes é interdependente

Riscos
Realização de testes
será fundamental
para o projeto

Geral
Percepção do grau
de dificuldade do
projeto

Obrigado! Questões?

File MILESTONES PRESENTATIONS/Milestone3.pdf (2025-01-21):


# Design and Development of a Modular Reconfigurable Aerial Vehicle

## Milestone 3

Grupo 6


107957 – Alexandre Silva
110180 – Magner Gusse

Grupo 6
107957 – Alexandre Silva
110180 – Magner Gusse
Pedro Casau


Orientador:


# Conteúdos

01 04

02 05


03 06

## Contexto

## WBS e objetivos da Milestone

## Progressos e Riscos

## Dificuldades e Aprendizagens

## Revisão dos objetivos e WBS

## Conclusão

# MISSION STATEMENT


# E OBJETIVOS

Construção de veículos aéreos que funcionam de forma individual, capazes de se juntar em voo formando configurações diferentes e capazes de em conjunto realizar diversas tarefas.

Uso de rotores uni-axiais e com voo estável e controlado fazendo uso do sistema Swashplateless para alcançar os 6 graus de liberdade do veículo.

# WBS Apresentada


## ELEMENTOS

DE

## LIGAÇÂO

# OBJECTIVOS PARA A MILESTONE

Impressão dos elementos de ligação e de swashplateless

TESTES Montagem da bancada de testes e iniciar os testes.


# PROGRESSOS E RISCOS

Estruturas de; ligação; Progresso; Obstáculos

Estruturas que permitirão
a ligação entre módulos

Modelos finalizados e
prontos para fabrico

• Medidas do mainframe do
módulo;
• Escolha do material para a
estrutura.

# PROGRESSOS E RISCOS

Swashplateless; Progresso; Modelo finalizado e preparado para impressão.; • Incompatibilidade com o motor resolvida; • Primeira impressão defeituosa.; Obstáculos

Sistema de direcionamento
do veículo.

# PROGRESSOS E RISCOS

Testes de propulsão; Progresso; Obstáculos

Com o objetivo de
determinar o máximo de
propulsão que podemos
adquirir com os motores e
determinar a massa da
estrutura final.

Fase final de preparação,
com os componentes
adquiridos e código
funcional.
Em fase de montagem da
bancada.

Tempo de chegada dos
componentes
Programação do
microcontrolador

# PROGRESSOS E RISCOS

Testes de; Swashplateless; Progresso; Obstáculos

Com o objetivo de testar o
sistema de direção do
veículo.

Dependente dos
progressos da montagem
e dos testes de propulsão.

• Necessidade de incorporar
um sensor de orientação
posicional;
• Programação do
microcontrolador

# TESTE PROPULSÃO


INICIAL

NOVA


# Propulsão-Load cell

Vantagens:
1. Apresenta um menor erro
2. Recolha de dados mais precisa e direta
3. Simples de montar

Desvantagens:
1. É necessário calibração
2. Utilizar software ArduinoIDE e entender o código

# Propulsão-Load cell Progresso



## FUNCIONAMENTO DO ESC E MOTOR

# DIFICULDADES ENCONTRADAS

Falta de familiarização com o Arduino IDE; Criação, percepção e interpretação de código para implementar nos testes.

A época de exames não foi tida em conta no planeamento de tarefas;
Demora na chegada de alguns componentes.

Falta de transmissor e recetor para colocar o ESC e o motor em funcionamento, o que implica que a implementação dos procedimentos deve recorrer a código.

PROGRAMAÇÃO | CUMPRIMENTO DOS PRAZOS

# APRENDIZAGENS

## USO DE UM MICROCONTROLADOR

O funcionamento e a importância de usar um microcontrolador como o Teensy ou Arduino.
Soldadura de componentes
eletrónicos e do microcontrolador

## CUMPRIMENTO DOS PRAZOS

Aspetos a considerar em
relação às tarefas a realizar e analise do grau de dificulade das mesmas.


## ELEMENTOS

DE

## LIGAÇÂO

# OBJECTIVOS PARA A MILESTONE-PROGRESSO

Impressão dos ligamentos de ligação e de swashplateless

Montar a bancada de testes e inicio dos TESTES mesmos

70%

50%


# OBJETIVO FINAL

Considerando as dificuldades e obstáculos enfrentados, os objetivos iniciais poderão não ser alcançados.

Criação de apenas um módulo independente com o Swashplateless funcional

https://www.youtube.com/watch?v=aEPf0QHVuMM&t=70s

# NOVA WBS


# CONCLUSÕES

Este projeto continua a suspreender pela dificuldade que apresenta a cada etapa que se passa

Não foi possível atingir os objetivos que traçados para esta Milestone


# OBRIGADO


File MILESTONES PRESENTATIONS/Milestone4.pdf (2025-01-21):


# Design and Development of a Modular Reconfigurable Aerial Vehicle

## Milestone 4

Grupo 6


107957 – Alexandre Silva
110180 – Magner Gusse

Grupo 6
107957 – Alexandre Silva
110180 – Magner Gusse
Pedro Casau


Orientador:


# INTRODUCTION


# MISSION STATEMENT & OBJECTIVES


https://www.youtube.com/watch?v=25zKLyOCA3A

# MISSION STATEMENT & OBJECTIVES


https://www.youtube.com/watch?v=fcradVE9uts

# MISSION STATEMENT & OBJECTIVES


https://www.youtube.com/watch?v=aEPf0QHVuMM&t=70s

# MISSION STATEMENT & OBJECTIVES


# Coupling Model


# COUPLING CONCEPT


# COUPLING CONCEPT


# THRUST STAND

https://youtube.com/shorts/JcyohlVHpi4?si=sUAPEv66bgu9Lc4i (https://youtube.com/shorts/JcyohlVHpi4?si=sUAPEv66bgu9Lc4i)

https://youtube.com/shorts/KsTUEmDCxvE?si=UuR2yHyfTJ3hSR7l (https://youtube.com/shorts/KsTUEmDCxvE?si=UuR2yHyfTJ3hSR7l)


# PROPULSION TESTS

PROPELLER-A

# PROPULSION TESTS


PROPELLER-B

# SWASHPLATELESS


https://www.youtube.com/watch?v=aEPf0QHVuMM&t=70s | 13

# WBS

Thurst

| Structure | Swasplateless


85% | 15% | 30%

Coupling Model
90%


# CONCLUSIONS


# THANK YOU!


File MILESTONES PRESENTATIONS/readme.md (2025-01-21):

[PT] Os ficheiros das apresentações 1 e 4(pptx) excedem o tamanho máximo permitido para upload na plataforma.

[EN] Files for presentations 1 and 4(pptx) exceed the maximum size allowed for upload to the platform.

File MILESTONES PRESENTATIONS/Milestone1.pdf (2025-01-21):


# Design and Development of a Modular Reconfigurable Aerial Vehicle

Grupo 6

107957 – Alexandre Silva
110180 – Magner Gusse

## Milestone 1

17/10/2023

# Contexto e problema

Mission Statement

Veículos aéreos modulares reconfiguráveis compreende-se como veículos independentes com capacidade de voar de forma autónoma e que conseguem montar e desmontar durante o voo. A sua versatilidade oferece várias aplicações como no transporte de cargas, devido a sua adaptabilidade às restrições. Tem ainda o potencial de ajudar em termos tecnológicos nas futuras montagens de estruturas no espaço.


https://medium.com/the-aerospace-corporation/onorbit-servicing-assembly-and-manufacturing-forspacecraft-86a2fbc317ee

# Reconfiguração


https://www.youtube.com/watch?v=25zKLyOCA3A

# Reconfiguração


https://www.youtube.com/watch?v=fcradVE9uts

Objetivos Secundários

- Rotores uni-axiais(Counter-Rotating).
- Demonstrar princípio científico e aplicabilidade.
- Otimização da estrutura.
- Extra: Ligação de um Payload de 200g.

# Objetivos

Objetivos Primários

- Desenvolver dois módulos independentes e capazes de realizar as reconfigurações em voo.
- Estudo, comparação e seleção dos metodos de acoplamento de módulos.

# Requisitos

Requisitos

Performance | Voo estável e controlado
| Reconfiguração em voo
| 6 graus de Liberdade
| Sistema Swashplateless
Reliability | 10 minutos de voo
| Estrutura resistente
| Aviónica protegida
| Reutilizável
Design | Simplicidade de Design Fácil montagem Fácil manutenção

# Swashplate


https://kc3dprint.com/products/swashplateleveling-centering-tool

Geralmente usado em helicópteros

https://www.youtube.com/watch?v=Qsr1bM-5s0g

Mecanicamente complexo

Recorre a pistões e/ou engrenagens para mudar o pitch das blades

Eletrónica simples


# Swashplateless


https://www.youtube.com/watch?v=aEPf0QHVuMM&t=70s

Mesma função que o swashplate; Mecanicamente mais simples; Pulsos(de corrente) que causam a aceleração/desaceleração das rpm levam o propeller pitch a mudar.; Eletrónicamente complexo

## Swashplateless


https://www.youtube.com/watch?v=aEPf0QHVuMM&t=70s

# Estrutura


10 https://mars.nasa.gov/resources/25043/mars-ingenuity-

helicopter-3d-model/

Counter rotating blades

Ter em conta o swashplateless

Pouca massa e maior resistência

# Mecanismos de Reconfiguração

Problemas:; Estrutural; Atuador linear; Ligação mecânica:

https://www.youtube.com/watch?v=25zKLyOCA3A

Juntar os módulos e depois separa-los

Ímanes ou eletroímanes

Forças de atração:

Objetivo:

Força dos ímanes; Massa dos componentes nas ligações mecânicas

https://www.youtube.com/watch?v=7iHZKMDvdNI

# Work Breakdown Structure


# Potenciais riscos

Riscos | Forma de mitigar
Falta de informação disponível | Realização de simulações e testes
Prazo do projeto | Cumprir os prazos apresentados no WBS
Custos das peças | Preparar um orçamento antecipadamente
Complexidade técnica | Minimizar o número de componentes
Segurança dos operadores | Realizar os testes em ambiente controlado

# Obrigado!

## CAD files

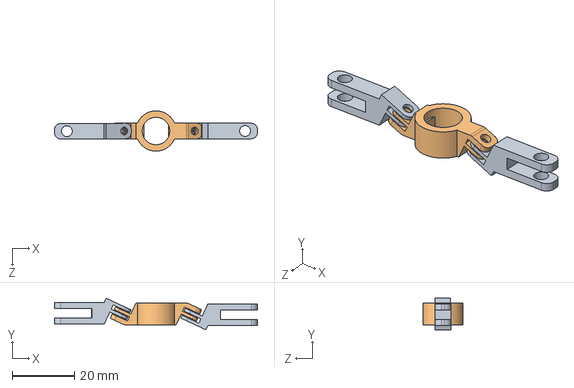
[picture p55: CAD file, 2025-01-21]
CAD/Swashplateless.SLDASM
65.4 x 10.2 x 13.0 mm
middle
lado x 2

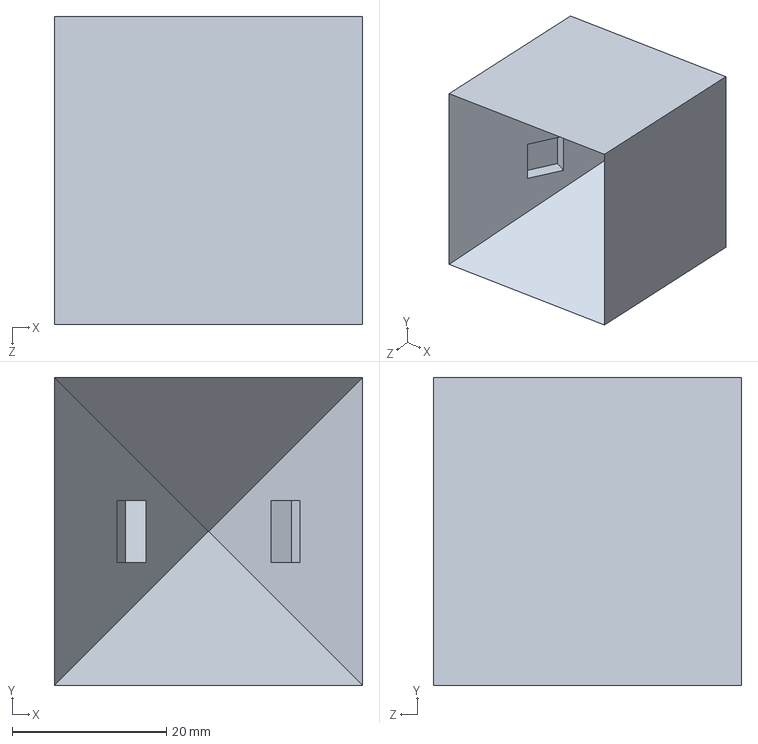
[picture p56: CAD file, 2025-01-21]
CAD/pecasdeligacao.SLDPRT
40.0 x 40.0 x 40.0 mm

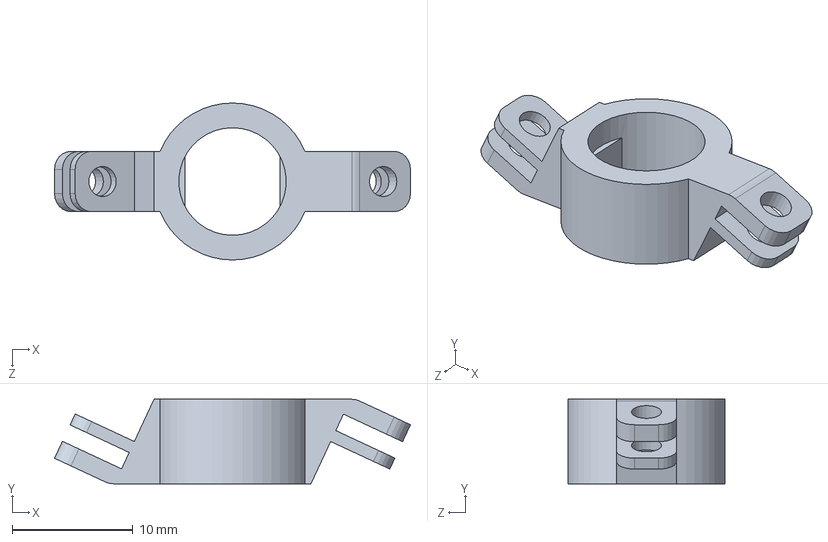
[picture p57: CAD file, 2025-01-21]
CAD/middle.SLDPRT
29.5 x 7.00 x 13.0 mm

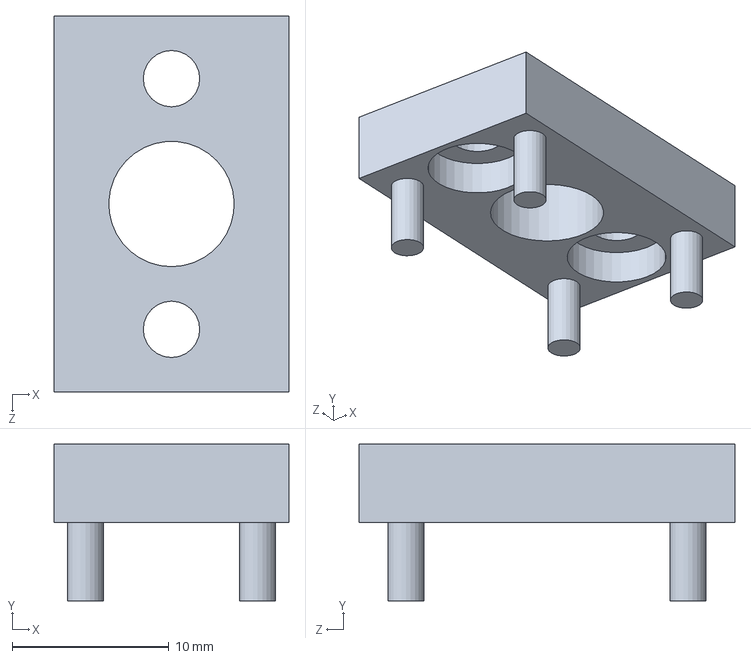
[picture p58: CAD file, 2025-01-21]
CAD/Holder_as5048.SLDPRT
15.0 x 10.0 x 24.0 mm

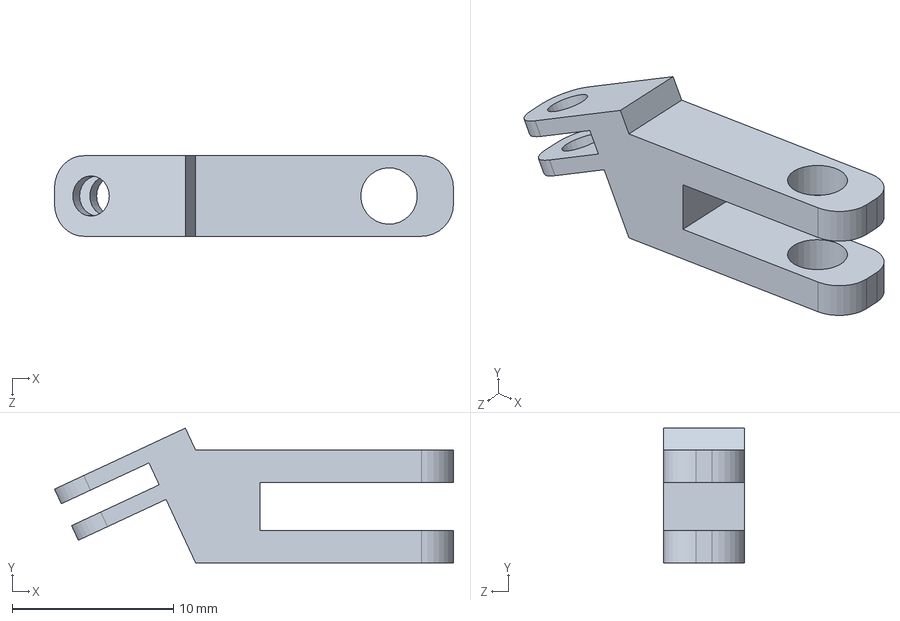
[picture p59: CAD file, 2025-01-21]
CAD/lado.SLDPRT
24.8 x 8.36 x 5.00 mm

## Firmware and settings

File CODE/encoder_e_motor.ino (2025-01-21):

#include <ams_as5048b.h>
#include <Wire.h>
//unit consts
#define U_RAW 1
#define U_TRN 2
#define U_DEG 3
#define U_RAD 4
#define U_GRAD 5
#define U_MOA 6
#define U_SOA 7
#define U_MILNATO 8
#define U_MILSE 9
#define U_MILRU 10

AMS_AS5048B mysensor;
// Motor variables
int motorSpeed = 127;
const int motorPin = 2; // Adjust this to your motor's pin
unsigned long lastTime;

void setup() {
	//Start serial
	Serial.begin(57600);
	while (!Serial) ; //wait until Serial ready
  // Set the I2C SDA and SCL pins for Wire2
	//Start Wire object. Unneeded here as this is done (optionally) by the AMS_AS5048B object (see lib code - #define USE_WIREBEGIN_ENABLED)
	Wire.begin();
	//init AMS_AS5048B object
	mysensor.begin();
	//consider the current position as zero
	mysensor.setZeroReg();

//Motor
  analogWriteFrequency(motorPin, 500);
  analogWriteResolution(8);
  analogWrite(motorPin, motorSpeed);
}

void loop() {
lastTime=millis();
	//print to serial the raw angle and degree angle every 2 seconds
	//print 2 times the exact same angle - only one measurement
	//Serial.print("Angle sensor raw : ");
//	Serial.println(mysensor.angleR(U_RAW, true), DEC);
  if (Serial.available()) {
    String input = Serial.readStringUntil('\n');
    //Serial.println(input[0]);
    processMotorInput(input[0]);
  }
 
  mysensor.angleR(U_RAW, true);
  //Serial.println(mysensor.getDiagReg());
	Serial.print("Angle degree : ");
	Serial.println(mysensor.angleR(U_DEG, false), DEC);

	while(millis()-lastTime<500);
}
void processMotorInput(char input) {
  switch (input) {
    case 'm':
      motorSpeed = min(motorSpeed + 5, 255);
      analogWrite(motorPin, motorSpeed);
      break;
    case 'n':
      motorSpeed = max(motorSpeed - 5, 127);
      analogWrite(motorPin, motorSpeed);
      break;
    case 's':
      motorSpeed = 127;
      analogWrite(motorPin, motorSpeed);
      break;
    default:
      Serial.println("Invalid input");
      break;
  }
}

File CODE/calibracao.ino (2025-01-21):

#include "HX711.h"
// HX711 circuit wiring
const int LOADCELL_DOUT_PIN = 24;
const int LOADCELL_SCK_PIN = 13;
const int Calibration_Weight = 490;
HX711 scale;
void setup() {
 Serial.begin(57600);
 scale.begin(LOADCELL_DOUT_PIN, LOADCELL_SCK_PIN);
 scale.set_scale();
 scale.tare();
 Serial.println("Calibration");
 Serial.println("Put a known weight on the scale");
 delay(5000);
 float x = scale.get_units(10);
 Serial.println(x);
 x = x / Calibration_Weight;
 scale.set_scale(x);
 Serial.println("Calibration finished...");
 delay(3000);
 }
void loop() {
 if (scale.is_ready()) {
 float reading = scale.get_units(10);
 Serial.print("HX711 reading: ");
 Serial.println(reading);
 } else {
 Serial.println("HX711 not found.");
 }
 delay(1000);
}
